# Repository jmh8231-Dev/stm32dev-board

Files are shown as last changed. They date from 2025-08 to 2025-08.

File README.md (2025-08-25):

# STM32F407ZETx 개발보드

**STM32F407ZETx** MCU를 중심으로 DS3231(RTC), VS1003(Audio Codec), microSD(4‑bit SDIO),
SN65HVD230(CAN), USB‑to‑TTL, **DP83848(Ethernet PHY)** 등을 온보드로 구성하고
대형 **브레드보드**와 12 V/5 V/3.3 V 전원 및 **SPI/I²C/PWM 헤더**를 둘러 배치한 실습·프로토타이핑 전용 보드입니다.

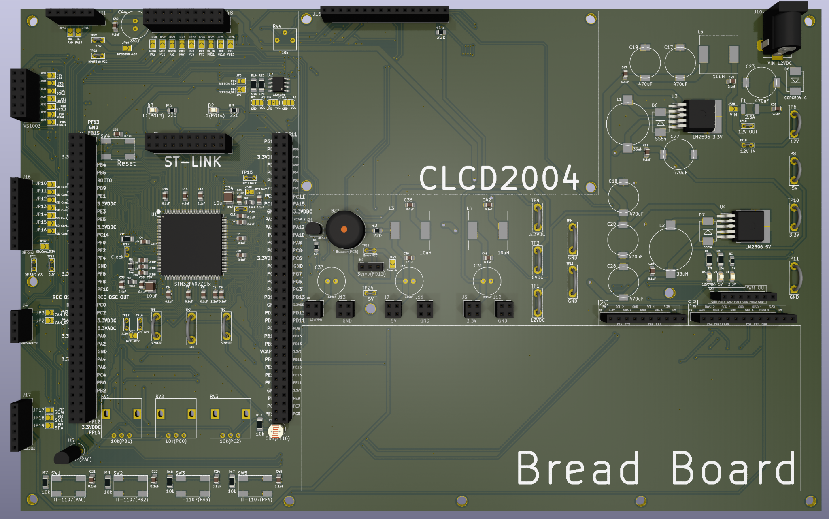
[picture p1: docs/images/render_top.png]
3D Render


---

## 1. 보드 하이라이트

- **MCU**: STM32F407ZETx (LQFP‑144), 8/16 MHz 외부 크리스털, ST‑LINK 20‑핀
- **전원 트리**: 12 V DC 잭 입력 → **LM2596‑5 V**, **LM2596‑3.3 V**
  - 브레드보드 주변에 **12 V / 5 V / 3.3 V 전원 핀** 다수 제공
- **통신/네트워킹**
  - **DP83848** 10/100 Ethernet PHY + RJ45
  - **SN65HVD230** CAN 트랜시버
  - **USB‑to‑TTL**(FT232RL 계열)
- **저장/오디오/시간**
  - **microSD(4‑bit SDIO)**, **VS1003** 오디오 코덱, **DS3231 RTC**
- **사용자 입출력**
  - **20×4 캐릭터 LCD(CLCD2004)** 장착 영역(백라이트 제어)
  - **브레드보드** 장착(보드 일체), 주변에 **SPI/I²C/PWM 헤더** 배치
  - 가변저항/버튼/버저 등 실습용 풋프린트
- **확장성**: 각 인터페이스에 테스트 포인트/점퍼 제공

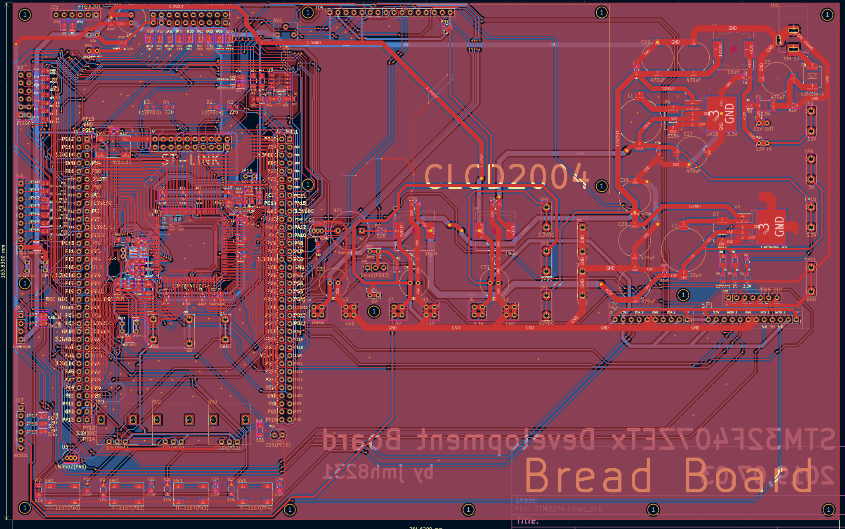
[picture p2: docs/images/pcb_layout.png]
PCB Layout


---

## 2. 주변장치 매핑 요약

| 기능 | 부품/모듈 | 인터페이스 | 비고 |
|---|---|---|---|
| Ethernet | TI **DP83848** | RMII/MII | RJ45, 링크 LED |
| CAN | TI **SN65HVD230** | CAN | 종단저항 점퍼 |
| Audio | **VS1003** | SPI / I²S | Sine test 지원 |
| Storage | microSD | **4‑bit SDIO** | 카드 감지/쓰기보호 |
| RTC | **DS3231** | I²C | 코인셀 백업 |
| USB‑UART | **FT232RL** | USB‑CDC | 부트 로그/쉘 |
| LCD | **CLCD2004** | 병렬 | 백라이트 제어 |
| Breadboard | 1열×2면 | — | SPI/I²C/PWM/전원 배치 |

---

## 3. 빠른 시작

1) 12 V 어댑터 연결 → 전원 LED 확인  
2) ST‑LINK 연결 후 예제 펌웨어 다운로드  
3) **Ethernet → CAN → SDIO → I²C(DS3231) → SPI(VS1003)** 순으로 브링업  
4) 브레드보드에 센서/액추에이터 연결 → SPI/I²C/PWM 헤더로 배선  
5) LCD 장착 후 상태/메뉴 표시 구현

---

## 4. 브링업 체크리스트

- **전원 리플/부하 테스트**(5 V/3.3 V)
- **SDIO 4‑bit**: HS 모드, 카드 감지/쓰기 보호 입력 확인
- **RMII/MII**: DP83848 링크/속도/MDIO 확인
- **CAN**: 루프백 → 실선 통신, 종단저항 설정
- **RTC**: DS3231 1 Hz/32 kHz, 온도 보정 레지스터 확인
- **VS1003**: SCI 레지스터 접근, sine test

---

## 5. 파일 트리

```text
stm32f407-devboard/
├─ README.md
└─ docs/
   └─ images/
      ├─ render_top.png
      ├─ pcb_layout.png
      └─ photo_top.jpg
```

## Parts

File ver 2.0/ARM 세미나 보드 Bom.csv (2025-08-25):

Reference | Qty | Value | DNP | Exclude from BOM | Exclude from Board | Footprint | Datasheet
BT1 | 1 | CR2032 |  |  |  | PCB:BAT-HLD-001 | ~
BZ1 | 1 | Buzzer(PE9) |  |  |  | Buzzer_Beeper:Buzzer_12x9.5RM7.6 | ~
C1,C7,C8,C9,C10,C11,C12,C13,C16,C20,C21,C25,C28,C29,C34,C36,C37,C39,C40,C41,C42,C43,C44,C46,C49,C50,C52,C53,C54,C56,C57,C59 | 32 | 0.1uF |  |  |  | Capacitor_SMD:C_0805_2012Metric | ~
C2,C15 | 2 | 0.01uF |  |  |  | Capacitor_SMD:C_0805_2012Metric | ~
C3,C6 | 2 | 2.2uF |  |  |  | Capacitor_SMD:C_0805_2012Metric | ~
C4,C5,C18,C19,C23,C24,C26,C27,C31,C32,C33,C35,C38,C47,C48,C51,C55 | 17 | 10uF |  |  |  | Capacitor_SMD:C_1206_3216Metric | ~
C14 | 1 | 1uF |  |  |  | Capacitor_SMD:C_0805_2012Metric | ~
C17,C22,C45,C58 | 4 | 470uF |  |  |  | PCB:MVG25WV470M | ~
C30 | 1 | 4.7uF |  |  |  | Capacitor_SMD:C_0805_2012Metric | ~
D1,D7 | 2 | M1 |  |  |  | Diode_SMD:D_SMA | ~
D2 | 1 | Rx |  |  |  | LED_SMD:LED_0805_2012Metric | ~
D3 | 1 | Tx |  |  |  | LED_SMD:LED_0805_2012Metric | ~
D4 | 1 | LD1(PB4) |  |  |  | LED_SMD:LED_0805_2012Metric | ~
D5 | 1 | LD2(PB5) |  |  |  | LED_SMD:LED_0805_2012Metric | ~
D6 | 1 | USB OC |  |  |  | LED_SMD:LED_0805_2012Metric | ~
D8 | 1 | 3.3V |  |  |  | LED_SMD:LED_0805_2012Metric | ~
D9 | 1 | 5V |  |  |  | LED_SMD:LED_0805_2012Metric | ~
DS1 | 1 | CLCD 2004 |  |  |  | PCB:LCD-20x4 | http://www.wincomlcd.com/pdf/WC1602A-SFYLYHTC06.pdf
EEPROM1 | 1 | AT24C256 |  |  |  | Package_SO:SOIC-8_3.9x4.9mm_P1.27mm | https://www.onsemi.cn/PowerSolutions/document/CAT24C256-D.PDF
F1 | 1 | 500mA |  |  |  | Inductor_SMD:L_1210_3225Metric | ~
FB2,FB3,FB4,FB5,FB6,FB7,FB8,FB9,FB10,FB11 | 10 | Bead |  |  |  | Inductor_SMD:L_0805_2012Metric | ~
J1 | 1 | ST-Link |  |  |  | Connector_IDC:IDC-Header_2x10_P2.54mm_Vertical | ~
J2 | 1 | USB Type C |  |  |  | Connector_USB:USB_C_Receptacle_HRO_TYPE-C-31-M-12 | https://www.usb.org/sites/default/files/documents/usb_type-c.zip
J3 | 1 | PIN OUT A |  |  |  | Connector_PinHeader_2.54mm:PinHeader_2x10_P2.54mm_Vertical | ~
J4 | 1 | PIN OUT B |  |  |  | Connector_PinHeader_2.54mm:PinHeader_2x10_P2.54mm_Vertical | ~
J5 | 1 | SG90 |  |  |  | Connector_PinHeader_2.54mm:PinHeader_1x03_P2.54mm_Vertical | ~
J6 | 1 | CAN |  |  |  | Connector_PinHeader_2.54mm:PinHeader_1x02_P2.54mm_Vertical | ~
J7 | 1 | USB_A |  |  |  | Connector_USB:USB_A_Connfly_DS1095 | ~
J8 | 1 | VS1003 |  |  |  | Connector_PinSocket_2.54mm:PinSocket_2x06_P2.54mm_Vertical | ~
JP1 | 1 | BOOT Mode |  |  |  | Jumper:SolderJumper-3_P1.3mm_Open_RoundedPad1.0x1.5mm | ~
Q1 | 1 | BSS138 |  |  |  | Package_TO_SOT_SMD:SOT-23 | https://www.onsemi.com/pub/Collateral/BSS138-D.PDF
R1,R7,R10,R11,R12,R13,R14,R15,R16,R19,R20,R23,R26,R27,R30,R33,R34,R35,R36,R41,R42,R43,R44,R45,R46,R50 | 26 | 10k |  |  |  | Resistor_SMD:R_0805_2012Metric | ~
R2,R3 | 2 | 5.1k |  |  |  | Resistor_SMD:R_0805_2012Metric | ~
R4,R5,R38,R39 | 4 | 22 |  |  |  | Resistor_SMD:R_0805_2012Metric | ~
R6,R29,R37,R40,R47,R48 | 6 | 4.7k |  |  |  | Resistor_SMD:R_0805_2012Metric | ~
R8,R9,R17,R18,R22,R49 | 6 | 1k |  |  |  | Resistor_SMD:R_0805_2012Metric | ~
R21 | 1 | 220 |  |  |  | Resistor_SMD:R_0805_2012Metric | ~
R24 | 1 | 120 |  |  |  | Resistor_SMD:R_0805_2012Metric | ~
R25 | 1 | 330 |  |  |  | Resistor_SMD:R_0805_2012Metric | ~
R28 | 1 | CDS(PC4) |  |  |  | OptoDevice:R_LDR_5.0x4.1mm_P3mm_Vertical | ~
R31 | 1 | 47k |  |  |  | Resistor_SMD:R_0805_2012Metric | ~
R32 | 1 | 620 |  |  |  | Resistor_SMD:R_0805_2012Metric | ~
RV1 | 1 | 10k |  |  |  | PCB:3362P-103LF | ~
RV2 | 1 | 10k(PA2) |  |  |  | PCB:RV09H20SQ-B10K | ~
RV3 | 1 | 10k(PA3) |  |  |  | PCB:RV09H20SQ-B10K | ~
RV4 | 1 | 10k(PA4) |  |  |  | PCB:RV09H20SQ-B10K | ~
SD1 | 1 | SD Card |  |  |  | PCB:AMPHENOL_GSD090012SEU
SW1 | 1 | Main MCU Reset |  |  |  | PCB:SW_SMD_IT-1107 | ~
SW2 | 1 | WiFi Module Reset |  |  |  | PCB:SW_SMD_IT-1107 | ~
SW3 | 1 | SW1(PC0) |  |  |  | PCB:SW_SMD_IT-1107 | ~
SW4 | 1 | SW2(PC1) |  |  |  | PCB:SW_SMD_IT-1107 | ~
SW5 | 1 | SW3(PC2) |  |  |  | PCB:SW_SMD_IT-1107 | ~
SW6 | 1 | SW4(PC3) |  |  |  | PCB:SW_SMD_IT-1107 | ~
Temp1,Temp2 | 2 | AS6221 |  |  |  | Package_CSP:WLCSP-6_1.4x1.0mm_P0.4mm
TP1 | 1 | TCXO 12MHz |  |  |  | TestPoint:TestPoint_Pad_D1.5mm | ~
TP2 | 1 | Buzzer(PE9) |  |  |  | TestPoint:TestPoint_Pad_D1.5mm | ~
TP3 | 1 | SG90(PB3) |  |  |  | TestPoint:TestPoint_Pad_D1.5mm | ~
TP4 | 1 | RTC BAT |  |  |  | TestPoint:TestPoint_Pad_D1.5mm | ~
TP5 | 1 | +3.3V |  |  |  | TestPoint:TestPoint_Pad_D1.5mm | ~
TP6,TP7,TP8,TP10 | 4 | GND |  |  |  | TestPoint:TestPoint_2Pads_Pitch5.08mm_Drill1.3mm | ~
TP9 | 1 | +5V |  |  |  | TestPoint:TestPoint_Pad_D1.5mm | ~
TP11,TP12 | 2 | GND | DNP |  | 기판에서 제외됨 | TestPoint:TestPoint_2Pads_Pitch5.08mm_Drill1.3mm | ~
U1 | 1 | STM32F405VGT6 |  |  |  | Package_QFP:LQFP-100_14x14mm_P0.5mm | https://www.st.com/resource/en/datasheet/stm32f405vg.pdf
U2 | 1 | 12MHz |  |  |  | PCB:ECS-TXO-2016
U3 | 1 | TVS |  |  |  | Package_TO_SOT_SMD:SOT-23-6 | https://www.we-online.com/components/products/datasheet/82400102.pdf
U4 | 1 | FT232RL |  |  |  | Package_SO:SSOP-28_5.3x10.2mm_P0.65mm | https://www.ftdichip.com/Support/Documents/DataSheets/ICs/DS_FT232R.pdf
U5 | 1 | ESP-12F |  |  |  | RF_Module:ESP-12E | http://wiki.ai-thinker.com/_media/esp8266/esp8266_series_modules_user_manual_v1.1.pdf
U6 | 1 | SN65HVD231 |  |  |  | Package_SO:SOIC-8_3.9x4.9mm_P1.27mm | http://www.ti.com/lit/ds/symlink/sn65hvd230.pdf
U7 | 1 | STMPS2141STR |  |  |  | Package_TO_SOT_SMD:SOT-23-5
U8 | 1 | DS3231M |  |  |  | Package_SO:SOIC-16W_7.5x10.3mm_P1.27mm | http://datasheets.maximintegrated.com/en/ds/DS3231.pdf
U9 | 1 | LM1117DT-3.3 |  |  |  | Package_TO_SOT_SMD:TO-252-3_TabPin2 | http://www.ti.com/lit/ds/symlink/lm1117.pdf

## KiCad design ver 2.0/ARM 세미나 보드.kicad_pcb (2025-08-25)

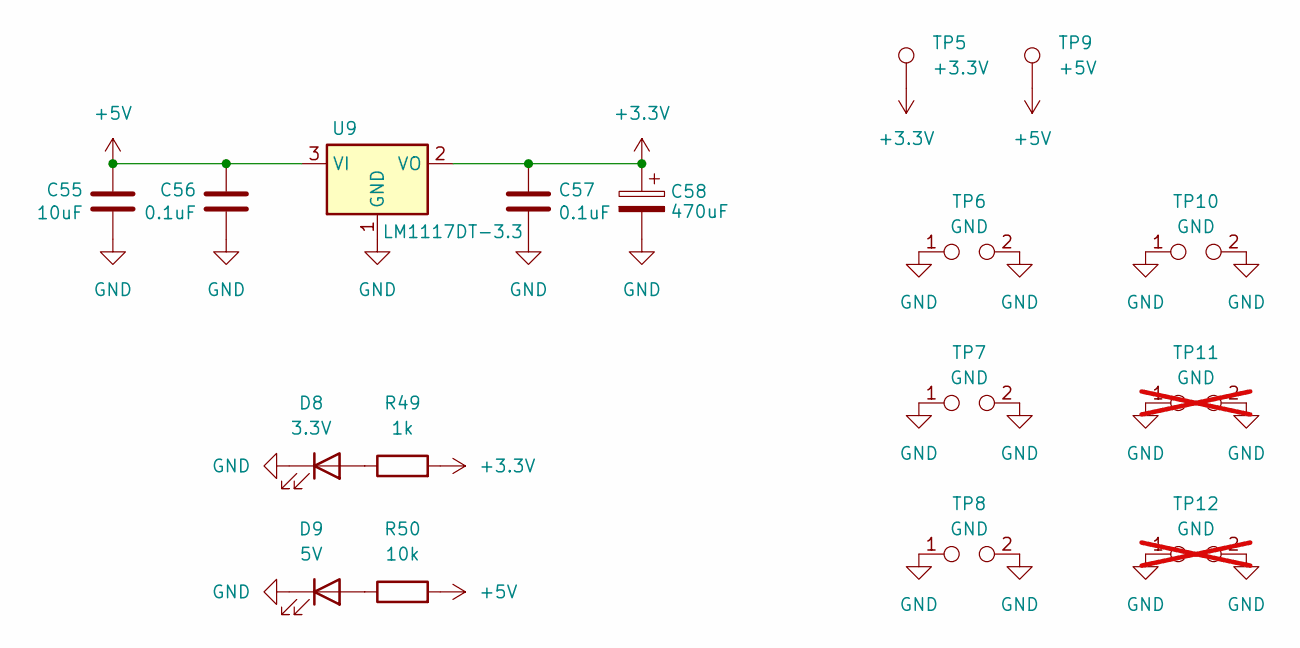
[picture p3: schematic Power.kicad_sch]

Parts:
C55: 10uF; C_1206_3216Metric
C56, C57: 0.1uF; C_0805_2012Metric
C58: 470uF; MVG25WV470M
D8: 3.3V; LED_0805_2012Metric
D9: 5V; LED_0805_2012Metric
R49: 1k; R_0805_2012Metric
R50: 10k; R_0805_2012Metric
TP5: +3.3V; TestPoint_Pad_D1.5mm
TP6, TP7, TP8, TP10: GND; TestPoint_2Pads_Pitch5.08mm_Drill1.3mm
TP9: +5V; TestPoint_Pad_D1.5mm
TP11, TP12: GND; TestPoint_2Pads_Pitch5.08mm_Drill1.3mm; not fitted
U9: LM1117DT-3.3; TO-252-3_TabPin2

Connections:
+3.3V: C57.2, C58.1, R49.2, TP5.1, U9.2 (VO); also elsewhere on the board
+5V: C55.2, C56.2, R50.2, TP9.1, U9.3 (VI); also elsewhere on the board
GND: C55.1, C56.1, C57.1, C58.2, D8.1 (K), D9.1 (K), TP6.1, TP6.2, TP7.1, TP7.2, TP8.1, TP8.2, TP10.1, TP10.2, TP11.1, TP11.2, TP12.1, TP12.2, U9.1 (GND); also elsewhere on the board
unnamed: D8.2 (A), R49.1
unnamed: D9.2 (A), R50.1

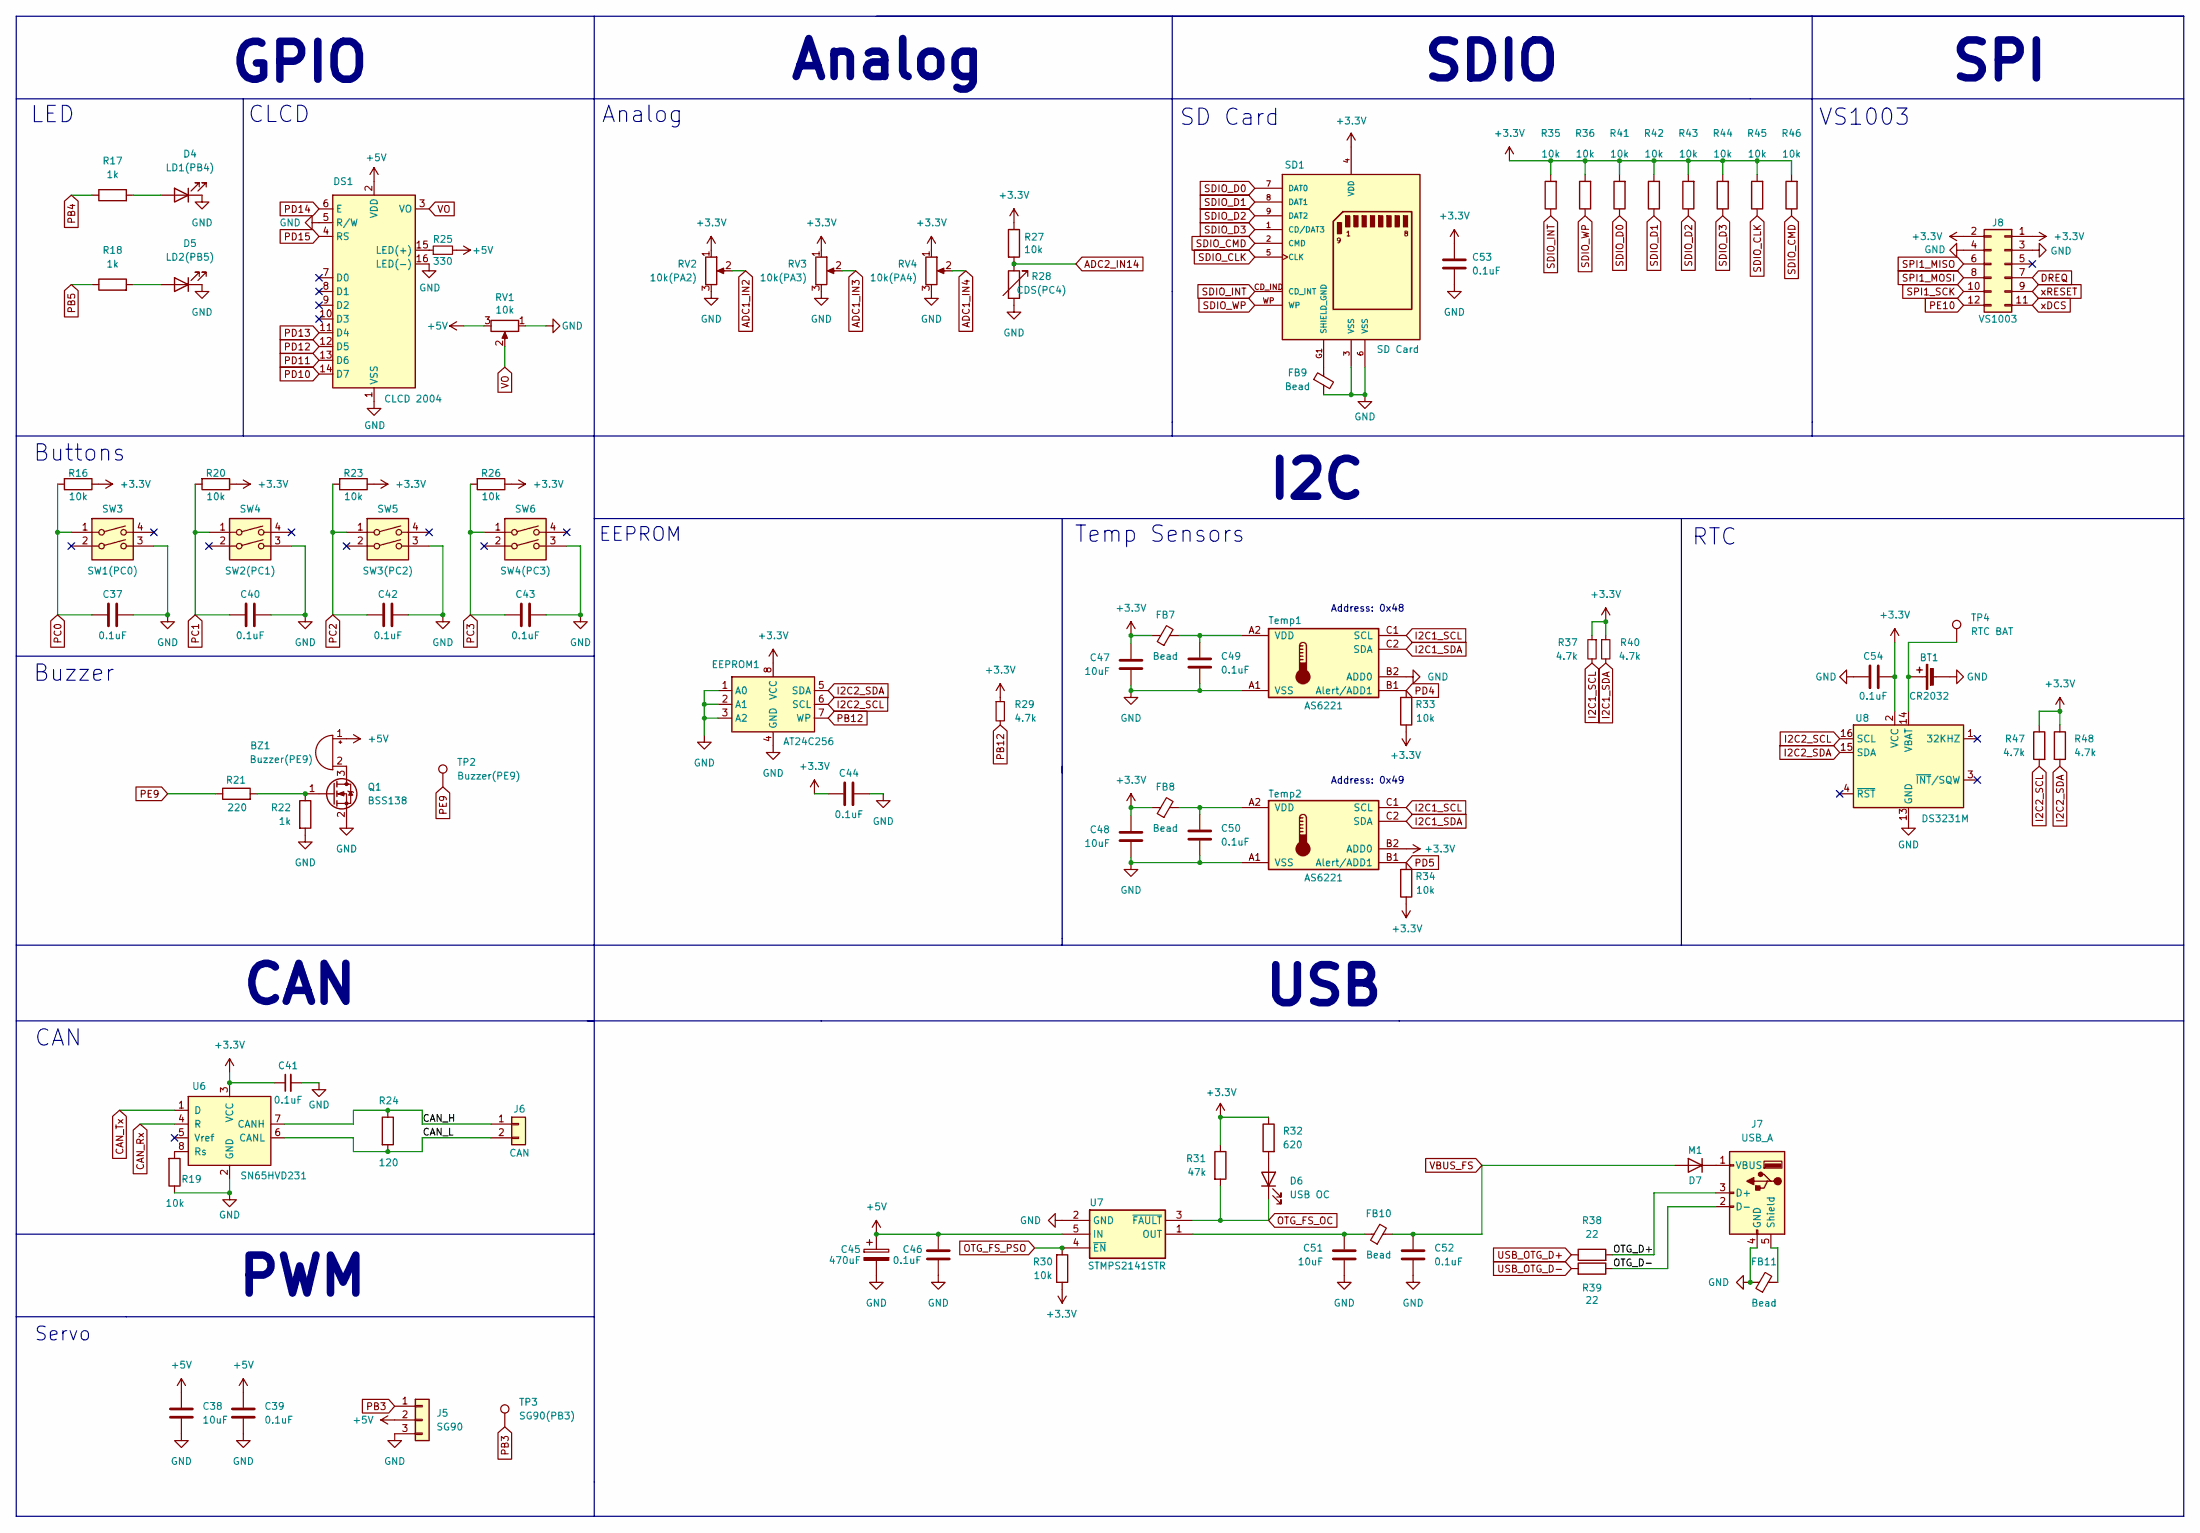
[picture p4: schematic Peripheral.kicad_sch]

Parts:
BT1: CR2032; BAT-HLD-001
BZ1: Buzzer(PE9); Buzzer_12x9.5RM7.6
C37, C39, C40, C41, C42, C43, C44, C46, C49, C50, C52, C53, C54: 0.1uF; C_0805_2012Metric
C38, C47, C48, C51: 10uF; C_1206_3216Metric
C45: 470uF; MVG25WV470M
D4: LD1(PB4); LED_0805_2012Metric
D5: LD2(PB5); LED_0805_2012Metric
D6: USB OC; LED_0805_2012Metric
D7: M1; D_SMA
DS1: CLCD 2004; LCD-20x4
EEPROM1: AT24C256; SOIC-8_3.9x4.9mm_P1.27mm
FB7, FB8, FB9, FB10, FB11: Bead; L_0805_2012Metric
J5: SG90; PinHeader_1x03_P2.54mm_Vertical
J6: CAN; PinHeader_1x02_P2.54mm_Vertical
J7: USB_A; USB_A_Connfly_DS1095
J8: VS1003; PinSocket_2x06_P2.54mm_Vertical
Q1: BSS138; SOT-23
R16, R19, R20, R23, R26, R27, R30, R33, R34, R35, R36, R41, R42, R43, R44, R45, R46: 10k; R_0805_2012Metric
R17, R18, R22: 1k; R_0805_2012Metric
R21: 220; R_0805_2012Metric
R24: 120; R_0805_2012Metric
R25: 330; R_0805_2012Metric
R28: CDS(PC4); R_LDR_5.0x4.1mm_P3mm_Vertical
R29, R37, R40, R47, R48: 4.7k; R_0805_2012Metric
R31: 47k; R_0805_2012Metric
R32: 620; R_0805_2012Metric
R38, R39: 22; R_0805_2012Metric
RV1: 10k; 3362P-103LF
RV2: 10k(PA2); RV09H20SQ-B10K
RV3: 10k(PA3); RV09H20SQ-B10K
RV4: 10k(PA4); RV09H20SQ-B10K
SD1: SD Card; AMPHENOL_GSD090012SEU; PARTREV E
SW3: SW1(PC0); SW_SMD_IT-1107
SW4: SW2(PC1); SW_SMD_IT-1107
SW5: SW3(PC2); SW_SMD_IT-1107
SW6: SW4(PC3); SW_SMD_IT-1107
TP2: Buzzer(PE9); TestPoint_Pad_D1.5mm
TP3: SG90(PB3); TestPoint_Pad_D1.5mm
TP4: RTC BAT; TestPoint_Pad_D1.5mm
Temp1, Temp2: AS6221; WLCSP-6_1.4x1.0mm_P0.4mm
U6: SN65HVD231; SOIC-8_3.9x4.9mm_P1.27mm
U7: STMPS2141STR; SOT-23-5
U8: DS3231M; SOIC-16W_7.5x10.3mm_P1.27mm

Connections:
+3.3V: C41.1, C44.1, C47.2, C48.2, C53.1, C54.2, EEPROM1.8 (VCC), FB7.1, FB8.1, J8.1, J8.2, R16.1, R20.1, R23.1, R26.1, R27.1, R29.1, R30.1, R31.1, R32.1, R33.1, R34.1, R35.2, R36.2, R37.1, R40.1, R41.2, R42.2, R43.2, R44.2, R45.2, R46.2, R47.1, R48.1, RV2.1, RV3.1, RV4.1, SD1.4 (VDD), Temp2.B2 (ADD0), U6.3 (VCC), U8.2 (VCC); also elsewhere on the board
+5V: BZ1.1 (+), C38.1, C39.1, C45.1, C46.1, DS1.2 (VDD), J5.2, R25.2, RV1.3, U7.5 (IN); also elsewhere on the board
/Peripheral/CAN_H: J6.1, R24.1, U6.7 (CANH)
/Peripheral/CAN_L: J6.2, R24.2, U6.6 (CANL)
/Peripheral/OTG_D+: J7.3 (D+), R38.2
/Peripheral/OTG_D-: J7.2 (D-), R39.1
ADC1_IN2: RV2.2; also elsewhere on the board
ADC1_IN3: RV3.2; also elsewhere on the board
ADC1_IN4: RV4.2; also elsewhere on the board
ADC2_IN14: R27.2, R28.1; also elsewhere on the board
CAN_Rx: U6.4 (R); also elsewhere on the board
CAN_Tx: U6.1 (D); also elsewhere on the board
DREQ: J8.7; also elsewhere on the board
GND: BT1.2 (-), C37.2, C38.2, C39.2, C40.2, C41.2, C42.2, C43.2, C44.2, C45.2, C46.2, C47.1, C48.1, C49.2, C50.2, C51.1, C52.2, C53.2, C54.1, D4.1 (K), D5.1 (K), DS1.1 (VSS), DS1.5 (R/W), DS1.16 (LED(-)), EEPROM1.1 (A0), EEPROM1.2 (A1), EEPROM1.3 (A2), EEPROM1.4 (GND), FB9.2, FB11.1, J5.3, J7.4 (GND), J8.3, J8.4, Q1.2 (S), R19.1, R22.2, R28.2, RV1.1, RV2.3, RV2.4, RV2.5, RV3.3, RV3.4, RV3.5, RV4.3, RV4.4, RV4.5, SD1.3 (VSS), SD1.6 (VSS), SW3.3, SW4.3, SW5.3, SW6.3, Temp1.A1 (VSS), Temp1.B2 (ADD0), Temp2.A1 (VSS), U6.2 (GND), U7.2 (GND), U8.5 (GND), U8.6 (GND), U8.7 (GND), U8.8 (GND), U8.9 (GND), U8.10 (GND), U8.11 (GND), U8.12 (GND), U8.13 (GND); also elsewhere on the board
I2C1_SCL: R37.2, Temp1.C1 (SCL), Temp2.C1 (SCL); also elsewhere on the board
I2C1_SDA: R40.2, Temp1.C2 (SDA), Temp2.C2 (SDA); also elsewhere on the board
I2C2_SCL: EEPROM1.6 (SCL), R47.2, U8.16 (SCL); also elsewhere on the board
I2C2_SDA: EEPROM1.5 (SDA), R48.2, U8.15 (SDA); also elsewhere on the board
unnamed: BT1.1 (+), TP4.1, U8.14 (VBAT)
unnamed: BZ1.2 (-), Q1.3 (D)
unnamed: D4.2 (A), R17.2
unnamed: D5.2 (A), R18.2
unnamed: D6.2 (A), R32.2
unnamed: D7.1 (K), J7.1 (VBUS)
unnamed: DS1.15 (LED(+)), R25.1
unnamed: FB11.2, J7.5 (Shield)
unnamed: Q1.1 (G), R21.2, R22.1
unnamed: C49.1, FB7.2, Temp1.A2 (VDD)
unnamed: C50.1, FB8.2, Temp2.A2 (VDD)
unnamed: R19.2, U6.8 (Rs)
unnamed: C51.2, FB10.1, U7.1 (OUT)
OTG_FS_OC: D6.1 (K), R31.2, U7.3 (~FAULT); also elsewhere on the board
OTG_FS_PSO: R30.2, U7.4 (~EN); also elsewhere on the board
PB3: J5.1, TP3.1; also elsewhere on the board
PB4: R17.1; also elsewhere on the board
PB5: R18.1; also elsewhere on the board
PB12: EEPROM1.7 (WP), R29.2; also elsewhere on the board
PC0: C37.1, R16.2, SW3.1; also elsewhere on the board
PC1: C40.1, R20.2, SW4.1; also elsewhere on the board
PC2: C42.1, R23.2, SW5.1; also elsewhere on the board
PC3: C43.1, R26.2, SW6.1; also elsewhere on the board
PD4: R33.2, Temp1.B1 (Alert/ADD1); also elsewhere on the board
PD5: R34.2, Temp2.B1 (Alert/ADD1); also elsewhere on the board
PD10: DS1.14 (D7); also elsewhere on the board
PD11: DS1.13 (D6); also elsewhere on the board
PD12: DS1.12 (D5); also elsewhere on the board
PD13: DS1.11 (D4); also elsewhere on the board
PD14: DS1.6 (E); also elsewhere on the board
PD15: DS1.4 (RS); also elsewhere on the board
PE9: R21.1, TP2.1; also elsewhere on the board
PE10: J8.12; also elsewhere on the board
SDIO_CLK: R45.1, SD1.5 (CLK); also elsewhere on the board
SDIO_CMD: R46.1, SD1.2 (CMD); also elsewhere on the board
SDIO_D0: R41.1, SD1.7 (DAT0); also elsewhere on the board
SDIO_D1: R42.1, SD1.8 (DAT1); also elsewhere on the board
SDIO_D2: R43.1, SD1.9 (DAT2); also elsewhere on the board
SDIO_D3: R44.1, SD1.1 (CD/DAT3); also elsewhere on the board
SDIO_INT: R35.1, SD1.CD_IND (CD_INT); also elsewhere on the board
SDIO_WP: R36.1, SD1.WP; also elsewhere on the board
SHIELD_GND: FB9.1, SD1.G1 (SHIELD_GND), SD1.G2 (SHIELD_GND), SD1.G3 (SHIELD_GND), SD1.G4 (SHIELD_GND)
SPI1_MISO: J8.6; also elsewhere on the board
SPI1_MOSI: J8.8; also elsewhere on the board
SPI1_SCK: J8.10; also elsewhere on the board
USB_OTG_D+: R38.1; also elsewhere on the board
USB_OTG_D-: R39.2; also elsewhere on the board
VBUS_FS: C52.1, D7.2 (A), FB10.2; also elsewhere on the board
VO: DS1.3 (VO), RV1.2
xDCS: J8.11; also elsewhere on the board
xRESET: J8.9; also elsewhere on the board

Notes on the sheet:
Address: 0x48
CLCD
Analog
Buttons
Buzzer
Servo
VS1003
RTC
EEPROM
LED
CAN
SPI
I2C
Temp Sensors
USB
SD Card
PWM
GPIO
SDIO
Address: 0x49

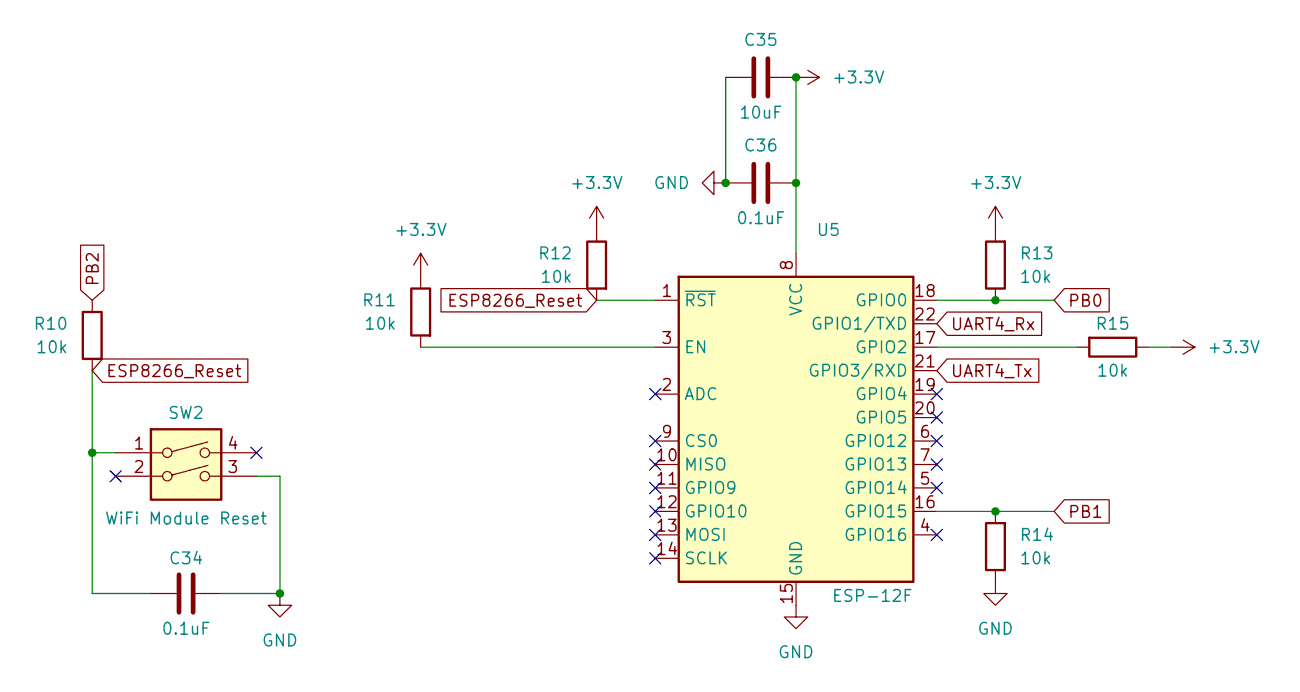
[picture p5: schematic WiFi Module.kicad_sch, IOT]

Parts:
C34, C36: 0.1uF; C_0805_2012Metric
C35: 10uF; C_1206_3216Metric
R10, R11, R12, R13, R14, R15: 10k; R_0805_2012Metric
SW2: WiFi Module Reset; SW_SMD_IT-1107
U5: ESP-12F; ESP-12E

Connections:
+3.3V: C35.2, C36.2, R11.1, R12.1, R13.2, R15.1, U5.8 (VCC); also elsewhere on the board
ESP8266_Reset: C34.1, R10.2, R12.2, SW2.1, U5.1 (~RST)
GND: C34.2, C35.1, C36.1, R14.1, SW2.3, U5.15 (GND); also elsewhere on the board
unnamed: R11.2, U5.3 (EN)
unnamed: R15.2, U5.17 (GPIO2)
PB0: R13.1, U5.18 (GPIO0); also elsewhere on the board
PB1: R14.2, U5.16 (GPIO15); also elsewhere on the board
PB2: R10.1; also elsewhere on the board
UART4_Rx: U5.22 (GPIO1/TXD); also elsewhere on the board
UART4_Tx: U5.21 (GPIO3/RXD); also elsewhere on the board

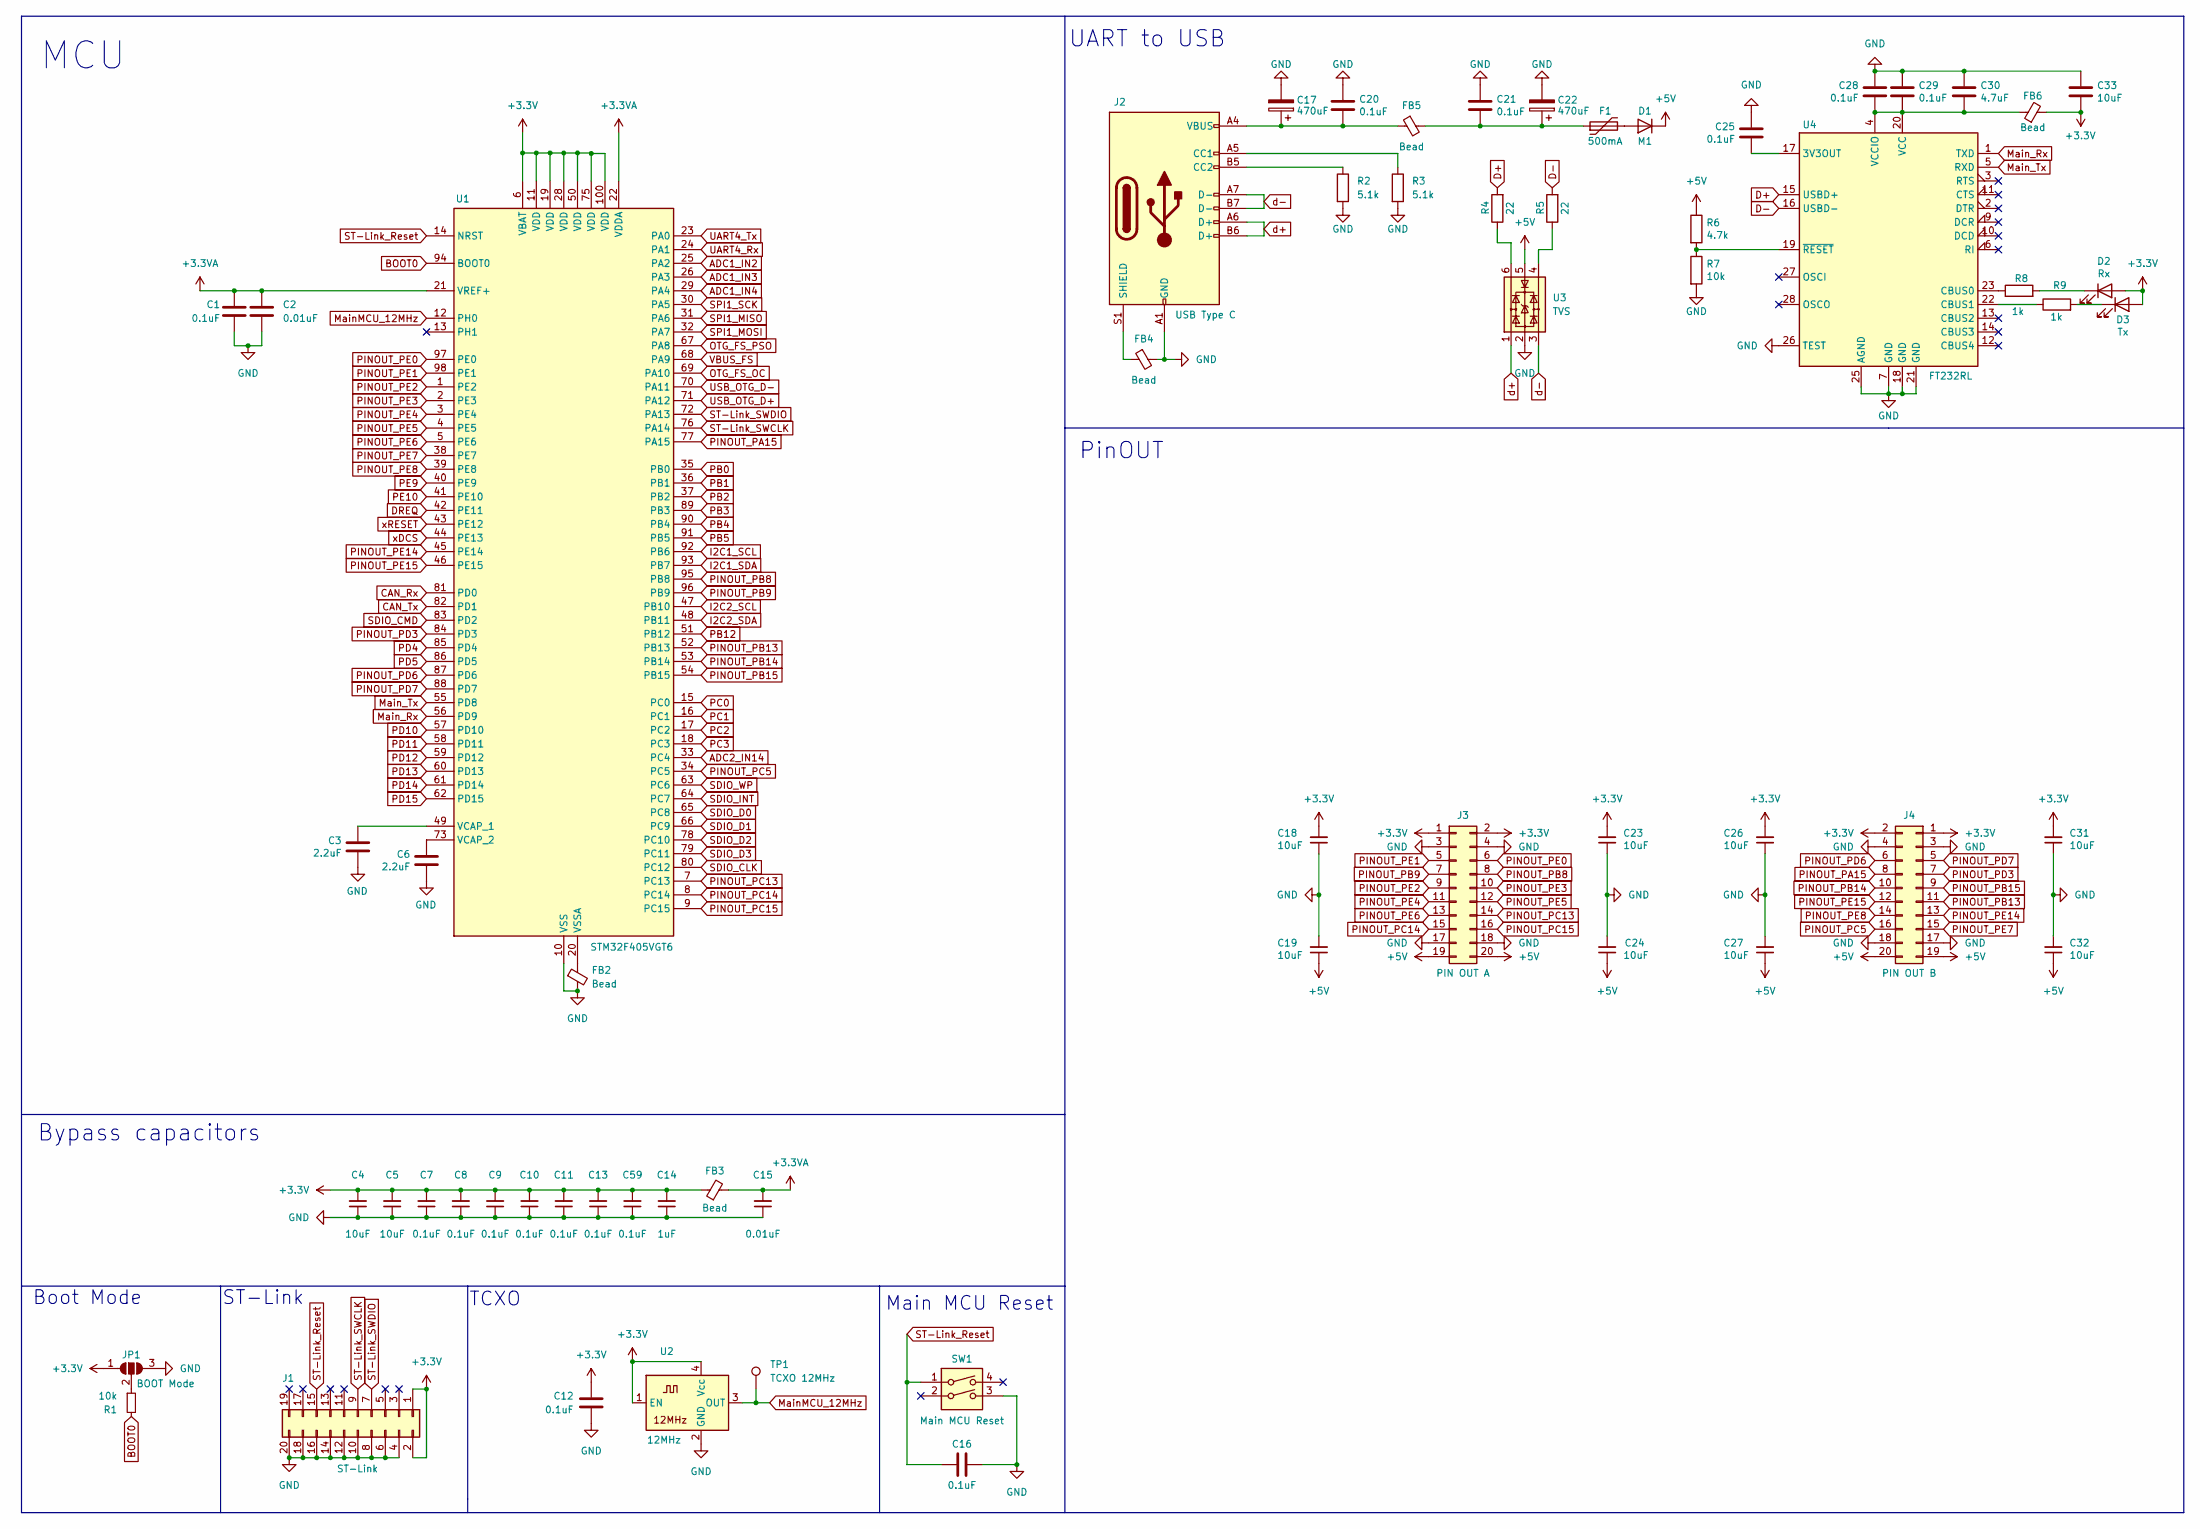
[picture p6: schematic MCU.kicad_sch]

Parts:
C1, C7, C8, C9, C10, C11, C12, C13, C16, C20, C21, C25, C28, C29, C59: 0.1uF; C_0805_2012Metric
C2, C15: 0.01uF; C_0805_2012Metric
C3, C6: 2.2uF; C_0805_2012Metric
C4, C5, C18, C19, C23, C24, C26, C27, C31, C32, C33: 10uF; C_1206_3216Metric
C14: 1uF; C_0805_2012Metric
C17, C22: 470uF; MVG25WV470M
C30: 4.7uF; C_0805_2012Metric
D1: M1; D_SMA
D2: Rx; LED_0805_2012Metric
D3: Tx; LED_0805_2012Metric
F1: 500mA; L_1210_3225Metric
FB2, FB3, FB4, FB5, FB6: Bead; L_0805_2012Metric
J1: ST-Link; IDC-Header_2x10_P2.54mm_Vertical
J2: USB Type C; USB_C_Receptacle_HRO_TYPE-C-31-M-12
J3: PIN OUT A; PinHeader_2x10_P2.54mm_Vertical
J4: PIN OUT B; PinHeader_2x10_P2.54mm_Vertical
JP1: BOOT Mode; SolderJumper-3_P1.3mm_Open_RoundedPad1.0x1.5mm
R1, R7: 10k; R_0805_2012Metric
R2, R3: 5.1k; R_0805_2012Metric
R4, R5: 22; R_0805_2012Metric
R6: 4.7k; R_0805_2012Metric
R8, R9: 1k; R_0805_2012Metric
SW1: Main MCU Reset; SW_SMD_IT-1107
TP1: TCXO 12MHz; TestPoint_Pad_D1.5mm
U1: STM32F405VGT6; LQFP-100_14x14mm_P0.5mm
U2: 12MHz; ECS-TXO-2016
U3: TVS; SOT-23-6
U4: FT232RL; SSOP-28_5.3x10.2mm_P0.65mm

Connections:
+3.3V: C4.2, C5.2, C7.2, C8.2, C9.2, C10.2, C11.2, C12.1, C13.2, C14.2, C18.2, C23.2, C26.2, C31.2, C33.1, C59.2, D2.2 (A), D3.2 (A), FB3.1, FB6.2, J1.1, J1.2, J3.1, J3.2, J4.1, J4.2, JP1.1 (A), U1.6 (VBAT), U1.11 (VDD), U1.19 (VDD), U1.28 (VDD), U1.50 (VDD), U1.75 (VDD), U1.100 (VDD), U2.1 (EN), U2.4 (Vcc); also elsewhere on the board
+3.3VA: C1.2, C2.2, C15.2, FB3.2, U1.21 (VREF+), U1.22 (VDDA)
+5V: C19.1, C24.1, C27.1, C32.1, D1.1 (K), J3.19, J3.20, J4.19, J4.20, R6.1, U3.5; also elsewhere on the board
ADC1_IN2: U1.25 (PA2); also elsewhere on the board
ADC1_IN3: U1.26 (PA3); also elsewhere on the board
ADC1_IN4: U1.29 (PA4); also elsewhere on the board
ADC2_IN14: U1.33 (PC4); also elsewhere on the board
BOOT0: R1.2, U1.94 (BOOT0)
CAN_Rx: U1.81 (PD0); also elsewhere on the board
CAN_Tx: U1.82 (PD1); also elsewhere on the board
D+: R4.2, U4.15 (USBD+)
D-: R5.2, U4.16 (USBD-)
DREQ: U1.42 (PE11); also elsewhere on the board
GND: C1.1, C2.1, C3.2, C4.1, C5.1, C6.2, C7.1, C8.1, C9.1, C10.1, C11.1, C12.2, C13.1, C14.1, C15.1, C16.2, C17.2, C18.1, C19.2, C20.2, C21.2, C22.2, C23.1, C24.2, C25.2, C26.1, C27.2, C28.2, C29.2, C30.2, C31.1, C32.2, C33.2, C59.1, FB2.2, FB4.2, J1.4, J1.6, J1.8, J1.10, J1.12, J1.14, J1.16, J1.18, J1.20, J2.A1 (GND), J2.A12 (GND), J2.B1 (GND), J2.B12 (GND), J3.3, J3.4, J3.17, J3.18, J4.3, J4.4, J4.17, J4.18, JP1.3 (B), R2.2, R3.2, R7.2, SW1.3, U1.10 (VSS), U1.27 (VSS), U1.74 (VSS), U1.99 (VSS), U2.2 (GND), U3.2, U4.7 (GND), U4.18 (GND), U4.21 (GND), U4.25 (AGND), U4.26 (TEST); also elsewhere on the board
I2C1_SCL: U1.92 (PB6); also elsewhere on the board
I2C1_SDA: U1.93 (PB7); also elsewhere on the board
I2C2_SCL: U1.47 (PB10); also elsewhere on the board
I2C2_SDA: U1.48 (PB11); also elsewhere on the board
MainMCU_12MHz: TP1.1, U1.12 (PH0), U2.3 (OUT)
Main_Rx: U1.56 (PD9), U4.1 (TXD)
Main_Tx: U1.55 (PD8), U4.5 (RXD)
unnamed: C17.1, C20.1, FB5.1, J2.A4 (VBUS), J2.A9 (VBUS), J2.B4 (VBUS), J2.B9 (VBUS)
unnamed: C21.1, C22.1, F1.1, FB5.2
unnamed: D1.2 (A), F1.2
unnamed: D2.1 (K), R8.2
unnamed: D3.1 (K), R9.2
unnamed: J2.A5 (CC1), R3.1
unnamed: J2.B5 (CC2), R2.1
unnamed: FB4.1, J2.S1 (SHIELD)
unnamed: JP1.2 (C), R1.1
unnamed: R4.1, U3.6
unnamed: R5.1, U3.4
unnamed: C3.1, U1.49 (VCAP_1)
unnamed: C6.1, U1.73 (VCAP_2)
unnamed: FB2.1, U1.20 (VSSA)
unnamed: C25.1, U4.17 (3V3OUT)
unnamed: R8.1, U4.23 (CBUS0)
unnamed: R9.1, U4.22 (CBUS1)
unnamed: C28.1, C29.1, C30.1, FB6.1, U4.4 (VCCIO), U4.20 (VCC)
unnamed: R6.2, R7.1, U4.19 (~RESET)
OTG_FS_OC: U1.69 (PA10); also elsewhere on the board
OTG_FS_PSO: U1.67 (PA8); also elsewhere on the board
PB0: U1.35 (PB0); also elsewhere on the board
PB1: U1.36 (PB1); also elsewhere on the board
PB2: U1.37 (PB2); also elsewhere on the board
PB3: U1.89 (PB3); also elsewhere on the board
PB4: U1.90 (PB4); also elsewhere on the board
PB5: U1.91 (PB5); also elsewhere on the board
PB12: U1.51 (PB12); also elsewhere on the board
PC0: U1.15 (PC0); also elsewhere on the board
PC1: U1.16 (PC1); also elsewhere on the board
PC2: U1.17 (PC2); also elsewhere on the board
PC3: U1.18 (PC3); also elsewhere on the board
PD4: U1.85 (PD4); also elsewhere on the board
PD5: U1.86 (PD5); also elsewhere on the board
PD10: U1.57 (PD10); also elsewhere on the board
PD11: U1.58 (PD11); also elsewhere on the board
PD12: U1.59 (PD12); also elsewhere on the board
PD13: U1.60 (PD13); also elsewhere on the board
PD14: U1.61 (PD14); also elsewhere on the board
PD15: U1.62 (PD15); also elsewhere on the board
PE9: U1.40 (PE9); also elsewhere on the board
PE10: U1.41 (PE10); also elsewhere on the board
PINOUT_PA15: J4.8, U1.77 (PA15)
PINOUT_PB8: J3.8, U1.95 (PB8)
PINOUT_PB9: J3.7, U1.96 (PB9)
PINOUT_PB13: J4.11, U1.52 (PB13)
PINOUT_PB14: J4.10, U1.53 (PB14)
PINOUT_PB15: J4.9, U1.54 (PB15)
PINOUT_PC5: J4.16, U1.34 (PC5)
PINOUT_PC13: J3.14, U1.7 (PC13)
PINOUT_PC14: J3.15, U1.8 (PC14)
PINOUT_PC15: J3.16, U1.9 (PC15)
PINOUT_PD3: J4.7, U1.84 (PD3)
PINOUT_PD6: J4.6, U1.87 (PD6)
PINOUT_PD7: J4.5, U1.88 (PD7)
PINOUT_PE0: J3.6, U1.97 (PE0)
PINOUT_PE1: J3.5, U1.98 (PE1)
PINOUT_PE2: J3.9, U1.1 (PE2)
PINOUT_PE3: J3.10, U1.2 (PE3)
PINOUT_PE4: J3.11, U1.3 (PE4)
PINOUT_PE5: J3.12, U1.4 (PE5)
PINOUT_PE6: J3.13, U1.5 (PE6)
PINOUT_PE7: J4.15, U1.38 (PE7)
PINOUT_PE8: J4.14, U1.39 (PE8)
PINOUT_PE14: J4.13, U1.45 (PE14)
PINOUT_PE15: J4.12, U1.46 (PE15)
SDIO_CLK: U1.80 (PC12); also elsewhere on the board
SDIO_CMD: U1.83 (PD2); also elsewhere on the board
SDIO_D0: U1.65 (PC8); also elsewhere on the board
SDIO_D1: U1.66 (PC9); also elsewhere on the board
SDIO_D2: U1.78 (PC10); also elsewhere on the board
SDIO_D3: U1.79 (PC11); also elsewhere on the board
SDIO_INT: U1.64 (PC7); also elsewhere on the board
SDIO_WP: U1.63 (PC6); also elsewhere on the board
SPI1_MISO: U1.31 (PA6); also elsewhere on the board
SPI1_MOSI: U1.32 (PA7); also elsewhere on the board
SPI1_SCK: U1.30 (PA5); also elsewhere on the board
ST-Link_Reset: C16.1, J1.15, SW1.1, U1.14 (NRST)
ST-Link_SWCLK: J1.9, U1.76 (PA14)
ST-Link_SWDIO: J1.7, U1.72 (PA13)
UART4_Rx: U1.24 (PA1); also elsewhere on the board
UART4_Tx: U1.23 (PA0); also elsewhere on the board
USB_OTG_D+: U1.71 (PA12); also elsewhere on the board
USB_OTG_D-: U1.70 (PA11); also elsewhere on the board
VBUS_FS: U1.68 (PA9); also elsewhere on the board
d+: J2.A6 (D+), J2.B6 (D+), U3.1
d-: J2.A7 (D-), J2.B7 (D-), U3.3
xDCS: U1.44 (PE13); also elsewhere on the board
xRESET: U1.43 (PE12); also elsewhere on the board

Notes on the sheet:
UART to USB
Bypass capacitors
TCXO
MCU
Main MCU Reset
Boot Mode
ST-Link
PinOUT

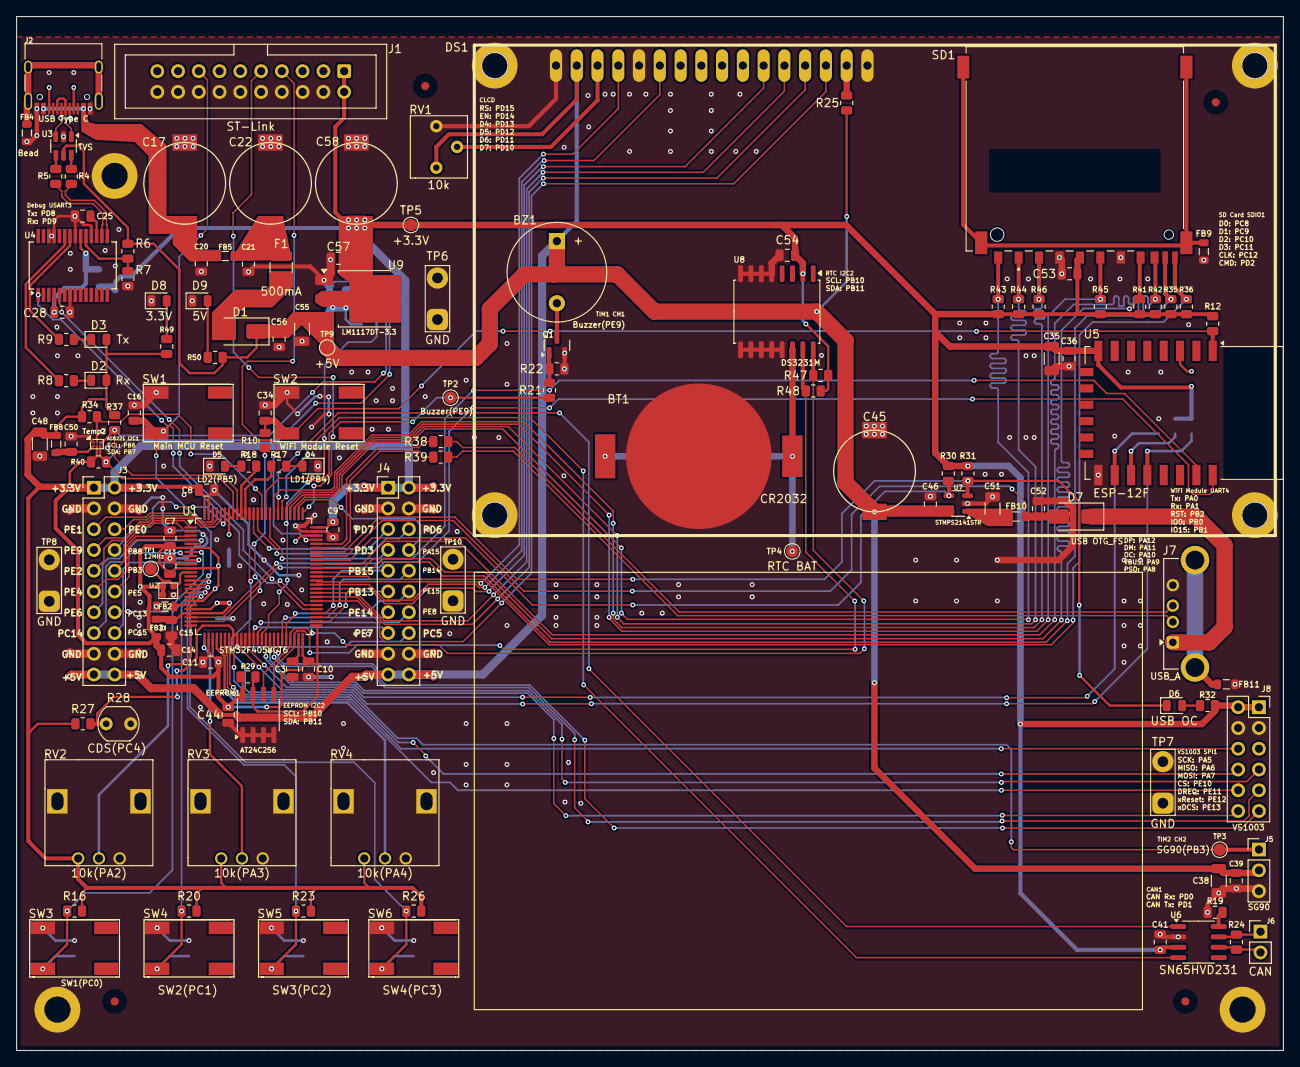
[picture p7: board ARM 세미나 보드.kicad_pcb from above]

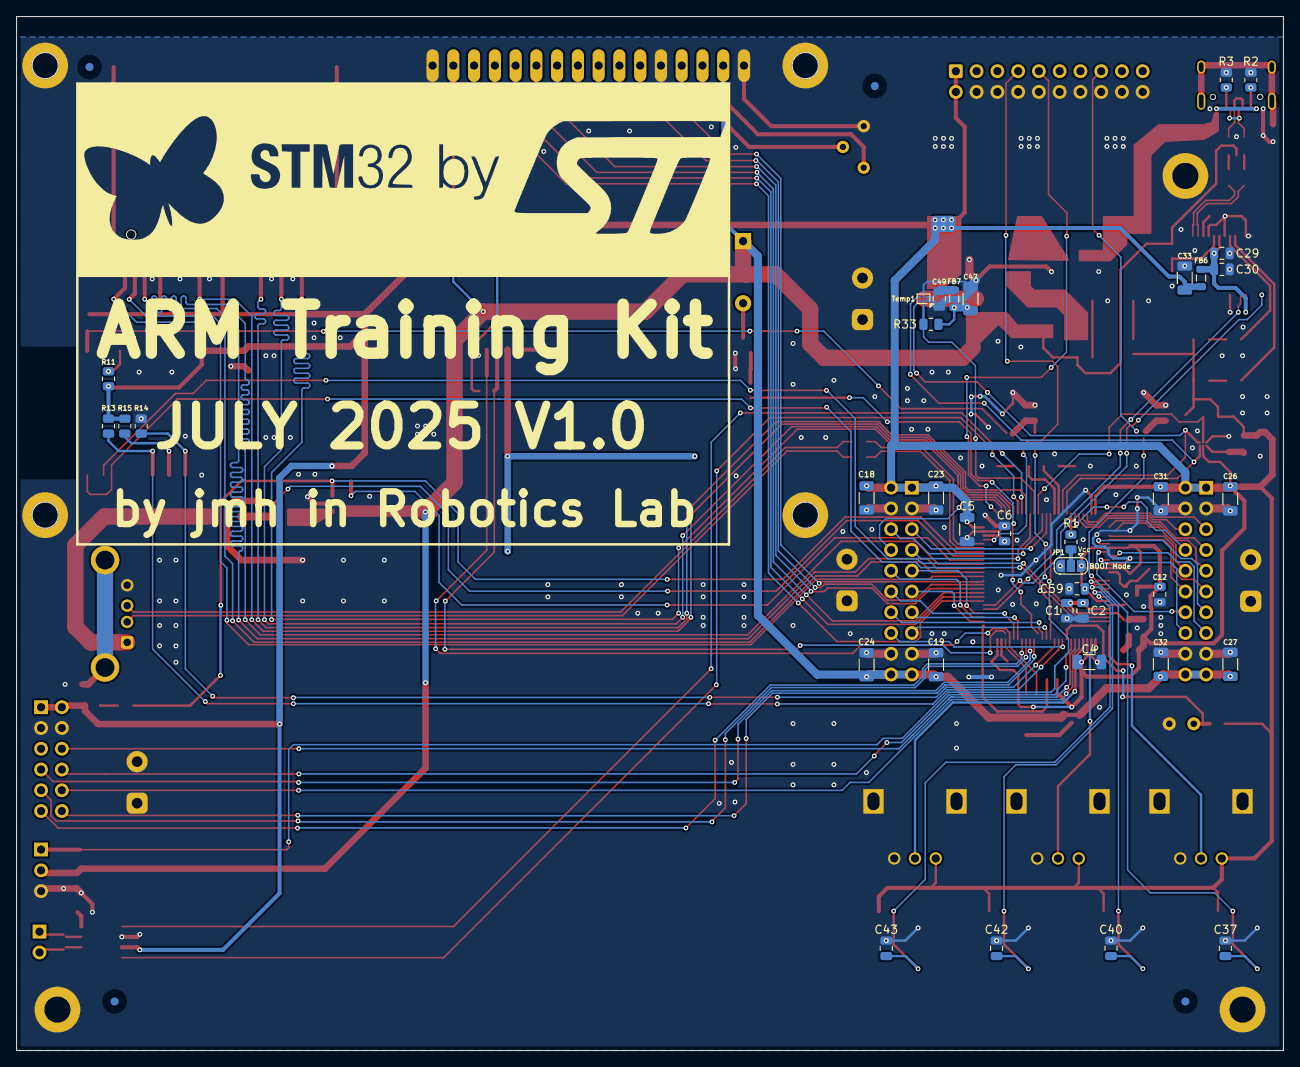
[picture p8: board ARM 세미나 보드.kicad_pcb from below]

Board: 2 copper layers, 155.0 x 126.5 mm, 175 parts (36 on the bottom side), 134 nets.

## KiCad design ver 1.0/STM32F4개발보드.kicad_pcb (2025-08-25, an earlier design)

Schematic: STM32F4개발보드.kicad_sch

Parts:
BZ1: Buzzer(PC6); Buzzer_12x9.5RM7.6
C1, C2: 2.2uF; C_0805_2012Metric_Pad1.15x1.40mm_HandSolder
C3, C4, C5, C6, C7, C8, C9, C10, C11, C12, C13, C14, C15, C16, C21, C22, C24, C25, C26, C29, C30, C35, C36, C38, C39, C40, C41, C42, C43, C45, C46, C47, C48: 0.1uF; C_0805_2012Metric_Pad1.15x1.40mm_HandSolder
C17, C18, C19, C20, C23, C27, C28: 470uF; MVG25WV470M
C31, C32, C33, C44: 330uF; c1
C34, C37: 10uF; C_1210_3225Metric_Pad1.42x2.65mm_HandSolder
D1: 3.3V; LED_0805_2012Metric_Pad1.15x1.40mm_HandSolder
D2: L2(PG14); LED_0805_2012Metric_Pad1.15x1.40mm_HandSolder
D3: L1(PG13); LED_0805_2012Metric_Pad1.15x1.40mm_HandSolder
D4: 5V; LED_0805_2012Metric_Pad1.15x1.40mm_HandSolder
D5: 12V(VIN); LED_0805_2012Metric_Pad1.15x1.40mm_HandSolder
D6, D7: SS54
D8: CGRC504-G; SS54
F1: 2.5A; Fuse_1812_4532Metric_Pad1.30x3.40mm_HandSolder
FB2: Bead
FB3: Bead; L_0805_2012Metric_Pad1.15x1.40mm_HandSolder
J1, J2: PinSocket_2x36_P2.54mm_Vertical
J3: I2C; PinSocket_1x10_P2.54mm_Vertical
J4: SN65HVD230; PinSocket_1x04_P2.54mm_Vertical
J5: SPI; PinSocket_1x12_P2.54mm_Vertical
J6: 3.3V; PinSocket_2x02_P2.54mm_Vertical
J7: 5V; PinSocket_2x02_P2.54mm_Vertical
J8: 12V(VIN); PinSocket_2x02_P2.54mm_Vertical
J9: ST-LINK; PinSocket_2x10_P2.54mm_Vertical
J10: VIN 12VDC; BarrelJack_Horizontal
J11, J12, J13: GND; PinSocket_2x02_P2.54mm_Vertical
J14: DP83848; PinSocket_2x10_P2.54mm_Vertical
J15: CLCD2004; PinSocket_1x16_P2.54mm_Vertical
J16: SD Card; PinSocket_1x09_P2.54mm_Vertical
J17: DS3231; PinSocket_1x06_P2.54mm_Vertical
J18: VS1003; PinSocket_2x06_P2.54mm_Vertical
J19: Servo(PD13); PinSocket_1x03_P2.54mm_Vertical
J20: PWM OUT; PinSocket_1x07_P2.54mm_Vertical
J21: FT232RL; PinSocket_1x06_P2.54mm_Vertical
JP2: CAN_RX; SolderJumper-2_P1.3mm_Open_TrianglePad1.0x1.5mm
JP3: CAN_TX; SolderJumper-2_P1.3mm_Open_TrianglePad1.0x1.5mm
JP4: A1; SolderJumper-3_P1.3mm_Open_RoundedPad1.0x1.5mm
JP5: A0; SolderJumper-3_P1.3mm_Open_RoundedPad1.0x1.5mm
JP6: A2; SolderJumper-3_P1.3mm_Open_RoundedPad1.0x1.5mm
JP7: EEPROM_SCL; SolderJumper-2_P1.3mm_Open_TrianglePad1.0x1.5mm
JP8: EEPROM_SDA; SolderJumper-2_P1.3mm_Open_TrianglePad1.0x1.5mm
JP9: Boot Mode; SolderJumper-3_P1.3mm_Open_RoundedPad1.0x1.5mm
JP10: SD Card_CD; SolderJumper-2_P1.3mm_Open_TrianglePad1.0x1.5mm
JP11: SD Card_D1; SolderJumper-2_P1.3mm_Open_TrianglePad1.0x1.5mm
JP12: SD Card_D2; SolderJumper-2_P1.3mm_Open_TrianglePad1.0x1.5mm
JP13: SD Card_D3; SolderJumper-2_P1.3mm_Open_TrianglePad1.0x1.5mm
JP14: SD Card_CLK; SolderJumper-2_P1.3mm_Open_TrianglePad1.0x1.5mm
JP15: SD Card_CMD; SolderJumper-2_P1.3mm_Open_TrianglePad1.0x1.5mm
JP16: SD Card_D0; SolderJumper-2_P1.3mm_Open_TrianglePad1.0x1.5mm
JP17: SQW; SolderJumper-2_P1.3mm_Open_TrianglePad1.0x1.5mm
JP18: SCL; SolderJumper-2_P1.3mm_Open_TrianglePad1.0x1.5mm
JP19: SDA; SolderJumper-2_P1.3mm_Open_TrianglePad1.0x1.5mm
JP20: MDIO; SolderJumper-2_P1.3mm_Open_TrianglePad1.0x1.5mm
JP21: OSCIN; SolderJumper-2_P1.3mm_Open_TrianglePad1.0x1.5mm
JP22: RX0; SolderJumper-2_P1.3mm_Open_TrianglePad1.0x1.5mm
JP23: TX_EN; SolderJumper-2_P1.3mm_Open_TrianglePad1.0x1.5mm
JP24: TX1; SolderJumper-2_P1.3mm_Open_TrianglePad1.0x1.5mm
JP25: TX0; SolderJumper-2_P1.3mm_Open_TrianglePad1.0x1.5mm
JP26: RX1; SolderJumper-2_P1.3mm_Open_TrianglePad1.0x1.5mm
JP27: CRS; SolderJumper-2_P1.3mm_Open_TrianglePad1.0x1.5mm
JP28: MDC; SolderJumper-2_P1.3mm_Open_TrianglePad1.0x1.5mm
JP29: MISO_1; SolderJumper-2_P1.3mm_Open_TrianglePad1.0x1.5mm
JP30: MOSI_1; SolderJumper-2_P1.3mm_Open_TrianglePad1.0x1.5mm
JP31: SCK_1; SolderJumper-2_P1.3mm_Open_TrianglePad1.0x1.5mm
JP32: CSS; SolderJumper-2_P1.3mm_Open_TrianglePad1.0x1.5mm
JP33: DREQ; SolderJumper-2_P1.3mm_Open_TrianglePad1.0x1.5mm
JP34: xRESET; SolderJumper-2_P1.3mm_Open_TrianglePad1.0x1.5mm
JP35: xDCS; SolderJumper-2_P1.3mm_Open_TrianglePad1.0x1.5mm
JP36: MCU DVCC; SolderJumper-2_P1.3mm_Open_TrianglePad1.0x1.5mm
JP37: MCU AVCC; SolderJumper-2_P1.3mm_Open_TrianglePad1.0x1.5mm
JP38: VIN; SolderJumper-2_P1.3mm_Open_TrianglePad1.0x1.5mm
JP39: SD_Card_3.3V; SolderJumper-2_P1.3mm_Open_TrianglePad1.0x1.5mm
JP40: DP83848 3.3V; SolderJumper-2_P1.3mm_Open_TrianglePad1.0x1.5mm
JP41: TX; SolderJumper-2_P1.3mm_Open_TrianglePad1.0x1.5mm
JP42: RX; SolderJumper-2_P1.3mm_Open_TrianglePad1.0x1.5mm
JP43: Servo 5V; SolderJumper-2_P1.3mm_Open_TrianglePad1.0x1.5mm
L1, L2: 33uH; SRR1806-330M
L3, L4, L5: 10uH; L_12x12mm_H6mm
Q1: BC547; TO-92_Inline
R1: 10k; R_0805_2012Metric_Pad1.15x1.40mm_HandSolder
R2, R3, R4, R16: 220; R_0805_2012Metric_Pad1.15x1.40mm_HandSolder
R5: 1k; R_0805_2012Metric_Pad1.15x1.40mm_HandSolder
R6, R7, R9, R10, R11, R12, R17: 10k; R_1206_3216Metric_Pad1.42x1.75mm_HandSolder
R8: 27k; R_1206_3216Metric_Pad1.42x1.75mm_HandSolder
R13, R14: 4.7k; R_1206_3216Metric_Pad1.42x1.75mm_HandSolder
R15: CDS(PF10); R_LDR_4.9x4.2mm_P2.54mm_Vertical
RV1: 10k(PB1); RV09H20SQ-B10K
RV2: 10k(PC0); RV09H20SQ-B10K
RV3: 10k(PC2); RV09H20SQ-B10K
RV4: 10k; 3362P-103LF
SW1: IT-1107(PA0); SW_SMD_IT-1107
SW2: IT-1107(PB2); SW_SMD_IT-1107
SW3: IT-1107(PA3); SW_SMD_IT-1107
SW4: Reset; SW_SMD_IT-1107
SW5: IT-1107(PF4); SW_SMD_IT-1107
TP1: 12VDC; TestPoint_Bridge_Pitch6.35mm_Drill1.3mm
TP2: 3.3VDDC; TestPoint_Bridge_Pitch6.35mm_Drill1.3mm
TP3: 5VDC; TestPoint_Bridge_Pitch6.35mm_Drill1.3mm
TP4: 3.3VDC; TestPoint_Bridge_Pitch6.35mm_Drill1.3mm
TP5: 3.3VADC; TestPoint_Bridge_Pitch6.35mm_Drill1.3mm
TP6: 12V; TestPoint_Bridge_Pitch6.35mm_Drill1.3mm
TP7, TP9, TP11, TP12: GND; TestPoint_Bridge_Pitch7.62mm_Drill1.3mm
TP8: 5V; TestPoint_Bridge_Pitch6.35mm_Drill1.3mm
TP10: 3.3V; TestPoint_Bridge_Pitch6.35mm_Drill1.3mm
TP13: Clock; TestPoint_Bridge_Pitch2.0mm_Drill0.7mm
TP14, TP17, TP20, TP23: 3.3V; TestPoint_Bridge_Pitch2.54mm_Drill0.7mm
TP15: MCU DVCC; TestPoint_Bridge_Pitch2.54mm_Drill0.7mm
TP16: MCU AVCC; TestPoint_Bridge_Pitch2.54mm_Drill0.7mm
TP18: 12V OUT; TestPoint_Bridge_Pitch2.54mm_Drill0.7mm
TP19: 12V IN; TestPoint_Bridge_Pitch2.54mm_Drill0.7mm
TP21: SD Card VCC; TestPoint_Bridge_Pitch2.54mm_Drill0.7mm
TP22: DP83848 VCC; TestPoint_Bridge_Pitch2.54mm_Drill0.7mm
TP24: 5V; TestPoint_Bridge_Pitch2.54mm_Drill0.7mm
TP25: Servo VCC; TestPoint_Bridge_Pitch2.54mm_Drill0.7mm
U1: STM32F407ZETx; LQFP-144_20x20mm_P0.5mm
U2: AT24C64; SOIC-8_3.9x4.9mm_P1.27mm
U3: LM2596 3.3V; TO-263-5_TabPin3
U4: LM2596 5V; TO-263-5_TabPin3
U5: LM35DZ(PA6); TO-92L_Inline
Y1: 12MHz; FT5HNBPK12.0-T1

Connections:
3.3VDDC: C4.2, C5.2, C6.2, C7.2, C8.2, C9.2, C10.2, C11.2, C12.2, C13.2, C14.2, C15.2, C34.1, C45.1, FB3.1, J1.6, J1.17, J1.18, J1.23, J1.36, J1.47, J1.58, J1.69, J2.6, J2.19, J2.32, J2.43, J2.55, J2.65, J9.1, J9.2, JP4.3, JP5.3, JP6.3, JP9.1, R7.1, R9.1, R10.1, R11.1, R13.2, R14.2, R17.1, TP2.1, U1.6 (VBAT), U1.17 (VDD), U1.30 (VDD), U1.39 (VDD), U1.52 (VDD), U1.62 (VDD), U1.72 (VDD), U1.84 (VDD), U1.95 (VDD), U1.108 (VDD), U1.121 (VDD), U1.131 (VDD), U1.143 (PDR_ON), U1.144 (VDD), U2.8 (VCC), U5.1 (+VS); also elsewhere on the board
3.3VOUT: C31.2, C35.1, C40.2, C41.1, C44.2, C46.1, J3.2, J3.9, J4.4, J5.2, J5.11, J6.1, J6.2, J6.3, J6.4, J18.1, J18.2, JP36.2 (B), JP37.2 (B), JP39.2 (B), JP40.1 (A), L4.2, TP4.1, TP14.1, TP17.1, TP20.1, TP23.1
5VOUT: C32.1, C39.1, J3.1, J3.10, J5.1, J5.12, J7.1, J7.2, J7.3, J7.4, J15.2, J17.5, JP43.2 (B), L3.2, R2.2, R16.2, RV4.3, TP3.1, TP24.1
12V: F1.1, JP38.2 (B), TP18.1
12VOUT: C17.1, C18.1, C19.1, C20.1, C33.1, C47.1, J8.1, J8.2, J8.3, J8.4, L5.2, R8.2, TP1.1, U3.1 (VIN), U4.1 (VIN)
32k: J17.1
+3V3: C27.1, C29.1, C42.1, L1.2, L4.1, R5.2, TP10.1, U3.4 (FB)
+5V: C28.1, C30.1, C36.1, L2.2, L3.1, R6.2, TP8.1, U4.4 (FB)
+12V: C43.1, JP38.1 (A), L5.1, TP6.1, TP19.1
A: J15.15, R16.1
A0: JP5.2, U2.1 (A0)
A1: JP4.2, U2.2 (A1)
A2: JP6.2, U2.3 (A2)
BOOT0: J1.11, JP9.2, U1.138 (BOOT0)
CD: J16.1, JP10.1 (A)
CLK: J16.5, JP14.1 (A)
CMD: J16.6, JP15.1 (A)
CRS: J14.14, JP27.2 (B)
CRX: J4.2, JP2.1 (A)
CTS: J21.2
CTX: J4.1, JP3.1 (A)
D0: J15.7
D1: J15.8
D2: J15.9
D3: J15.10
DP83848_Power: J14.19, J14.20, JP40.2 (B), TP22.1
DREQ: J18.7, JP33.1 (A)
DTR: J21.6
GND: C1.2, C2.2, C4.1, C5.1, C6.1, C7.1, C8.1, C9.1, C10.1, C11.1, C12.1, C13.1, C14.1, C15.1, C17.2, C18.2, C19.2, C20.2, C21.1, C22.1, C23.2, C24.1, C25.1, C26.2, C27.2, C28.2, C29.2, C30.2, C31.1, C32.2, C33.2, C34.2, C36.2, C39.2, C40.1, C41.2, C42.2, C43.2, C44.1, C45.2, C46.2, C47.2, C48.1, D1.1 (K), D2.1 (K), D3.1 (K), D4.1 (K), D5.1 (K), D6.2 (A), D7.2 (A), J1.3, J1.33, J1.55, J1.70, J2.7, J2.20, J2.33, J2.44, J2.66, J3.5, J3.6, J4.3, J5.6, J5.7, J9.3, J9.5, J9.7, J9.9, J9.11, J9.13, J9.15, J9.17, J9.19, J10.2, J10.3, J11.1, J11.2, J11.3, J11.4, J12.1, J12.2, J12.3, J12.4, J13.1, J13.2, J13.3, J13.4, J14.17, J14.18, J15.1, J15.5, J15.16, J16.8, J17.6, J18.3, J18.4, J19.3, J20.1, J20.3, J20.5, J20.7, J21.1, JP4.1, JP5.1, JP6.1, JP9.3, Q1.1 (C), R1.2, R15.2, RV1.1, RV2.1, RV3.1, RV4.1, SW1.3, SW1.4, SW2.3, SW2.4, SW3.3, SW3.4, SW4.3, SW4.4, SW5.3, SW5.4, TP7.1, TP9.1, TP11.1, TP12.1, U1.16 (VSS), U1.38 (VSS), U1.51 (VSS), U1.61 (VSS), U1.83 (VSS), U1.94 (VSS), U1.107 (VSS), U1.120 (VSS), U1.130 (VSS), U2.4 (GND), U2.7 (WP), U3.3 (GND), U3.5 (~ON/OFF), U4.3 (GND), U4.5 (~ON/OFF), U5.3 (GND); also elsewhere on the board
GNDA: C3.2, C16.1, C35.2, C37.2, C38.2, J1.50, U1.31 (VSSA), Y1.1 (NC), Y1.2 (GND); also elsewhere on the board
MDC: J14.16, JP28.2 (B)
MDIO: J14.15, JP20.2 (B)
MISO_1: J1.7, J5.4, JP29.2 (B), U1.134 (PB4)
MISO_2: J2.52, J5.9, U1.75 (PB14)
MOSI_1: J1.10, J5.3, JP30.2 (B), U1.135 (PB5)
MOSI_2: J1.48, J5.10, U1.29 (PC3)
unnamed: BZ1.1 (-), R2.1
unnamed: BZ1.2 (+), Q1.3 (E)
unnamed: C23.1, C26.1, D8.1 (K), F1.2
unnamed: D1.2 (A), R5.1
unnamed: D2.2 (A), R3.2
unnamed: D3.2 (A), R4.2
unnamed: D4.2 (A), R6.1
unnamed: D5.2 (A), R8.1
unnamed: D6.1 (K), L1.1, U3.2 (OUT)
unnamed: D7.1 (K), L2.1, U4.2 (OUT)
unnamed: D8.2 (A), J10.1
unnamed: FB3.2, JP36.1 (A), TP15.1
unnamed: J18.6, JP29.1 (A)
unnamed: J18.8, JP30.1 (A)
unnamed: J18.10, JP31.1 (A)
unnamed: J18.12, JP32.1 (A)
unnamed: J19.2, JP43.1 (A), TP25.1
OSCIN: J14.13, JP21.2 (B)
PA0: C21.2, J1.51, R7.2, SW1.1, SW1.2, U1.34 (PA0)
PA1: J1.54, JP21.1 (A), U1.35 (PA1)
PA2: J1.53, JP20.1 (A), U1.36 (PA2)
PA3: C24.2, J1.56, R10.2, SW3.1, SW3.2, U1.37 (PA3)
PA4: J1.57, U1.40 (PA4)
PA5: J1.60, J5.5, JP31.2 (B), U1.41 (PA5)
PA6: J1.59, U1.42 (PA6), U5.2 (VOUT)
PA7: J1.62, JP27.1 (A), U1.43 (PA7)
PA8: J2.27, U1.100 (PA8)
PA9: J2.26, JP42.2 (B), U1.101 (PA9)
PA10: J2.25, JP41.2 (B), U1.102 (PA10)
PA11: J2.24, JP2.2 (B), U1.103 (PA11)
PA12: J2.23, JP3.2 (B), U1.104 (PA12)
PA15: J2.17, J20.2, U1.110 (PA15)
PB0: J1.63, U1.46 (PB0)
PB1: J1.66, RV1.2, U1.47 (PB1)
PB2: C22.2, J1.65, R9.2, SW2.1, SW2.2, U1.48 (PB2)
PB6: J1.9, J3.4, JP7.2 (B), JP18.2 (B), U1.136 (PB6)
PB7: J1.12, J3.3, JP8.2 (B), JP19.2 (B), U1.137 (PB7)
PB8: J1.14, U1.139 (PB8)
PB9: J1.13, JP32.2 (B), U1.140 (PB9)
PB10: J2.58, J5.8, U1.69 (PB10)
PB11: J2.57, JP23.1 (A), U1.70 (PB11)
PB12: J2.54, JP25.1 (A), U1.73 (PB12)
PB13: J2.53, JP24.1 (A), U1.74 (PB13)
PB15: J2.51, U1.76 (PB15)
PC0: J1.43, RV2.2, U1.26 (PC0)
PC1: J1.46, JP28.1 (A), U1.27 (PC1)
PC2: J1.45, RV3.2, U1.28 (PC2)
PC4: J1.61, JP22.1 (A), U1.44 (PC4)
PC5: J1.64, JP26.1 (A), U1.45 (PC5)
PC6: J2.31, Q1.2 (B), R1.1, U1.96 (PC6)
PC7: J2.30, U1.97 (PC7)
PC8: J2.29, JP16.2 (B), U1.98 (PC8)
PC9: J2.28, JP11.2 (B), U1.99 (PC9)
PC10: J2.16, JP12.2 (B), U1.111 (PC10)
PC11: J2.15, JP13.2 (B), U1.112 (PC11)
PC12: J2.14, JP14.2 (B), U1.113 (PC12)
PC13: J1.26, U1.7 (PC13)
PC14: J1.25, U1.8 (PC14)
PC15: J1.28, U1.9 (PC15)
PD0: J2.13, U1.114 (PD0)
PD1: J2.12, JP10.2 (B), U1.115 (PD1)
PD2: J2.11, JP15.2 (B), U1.116 (PD2)
PD3: J2.10, U1.117 (PD3)
PD4: J2.9, U1.118 (PD4)
PD5: J2.8, U1.119 (PD5)
PD6: J2.5, U1.122 (PD6)
PD7: J2.4, U1.123 (PD7)
PD8: J2.50, U1.77 (PD8)
PD9: J2.49, U1.78 (PD9)
PD10: J2.48, U1.79 (PD10)
PD11: J2.47, U1.80 (PD11)
PD12: J2.46, J20.6, U1.81 (PD12)
PD13: J2.45, J19.1, U1.82 (PD13)
PD14: J2.42, J20.4, U1.85 (PD14)
PD15: J2.41, J15.14, U1.86 (PD15)
PE0: J1.16, U1.141 (PE0)
PE1: J1.15, U1.142 (PE1)
PE2: J1.20, U1.1 (PE2)
PE3: J1.19, U1.2 (PE3)
PE4: J1.22, U1.3 (PE4)
PE5: J1.21, U1.4 (PE5)
PE6: J1.24, U1.5 (PE6)
PE7: J2.69, U1.58 (PE7)
PE8: J2.68, U1.59 (PE8)
PE9: J2.67, U1.60 (PE9)
PE10: J2.64, U1.63 (PE10)
PE11: J2.63, U1.64 (PE11)
PE12: J2.62, U1.65 (PE12)
PE13: J2.61, U1.66 (PE13)
PE14: J2.60, U1.67 (PE14)
PE15: J2.59, U1.68 (PE15)
PF0: J1.27, J3.7, U1.10 (PF0)
PF1: J1.30, J3.8, U1.11 (PF1)
PF2: J1.29, U1.12 (PF2)
PF3: J1.32, U1.13 (PF3)
PF4: C48.2, J1.31, R17.2, SW5.1, SW5.2, U1.14 (PF4)
PF5: J1.34, JP17.2 (B), U1.15 (PF5)
PF6: J1.35, JP33.2 (B), U1.18 (PF6)
PF7: J1.38, JP34.2 (B), U1.19 (PF7)
PF8: J1.37, JP35.2 (B), U1.20 (PF8)
PF9: J1.40, U1.21 (PF9)
PF10: J1.39, R12.1, R15.1, U1.22 (PF10)
PF11: J1.68, U1.49 (PF11)
PF12: J1.67, U1.50 (PF12)
PF13: J1.72, U1.53 (PF13)
PF14: J1.71, U1.54 (PF14)
PF15: J2.72, U1.55 (PF15)
PG0: J2.71, U1.56 (PG0)
PG1: J2.70, U1.57 (PG1)
PG2: J2.40, J15.13, U1.87 (PG2)
PG3: J2.39, J15.12, U1.88 (PG3)
PG4: J2.38, J15.11, U1.89 (PG4)
PG5: J2.37, J15.6, U1.90 (PG5)
PG6: J2.36, J15.4, U1.91 (PG6)
PG7: J2.35, U1.92 (PG7)
PG8: J2.34, U1.93 (PG8)
PG9: J2.3, U1.124 (PG9)
PG10: J2.2, U1.125 (PG10)
PG11: J2.1, U1.126 (PG11)
PG12: J1.2, U1.127 (PG12)
PG13: J1.1, R4.1, U1.128 (PG13)
PG14: J1.4, R3.1, U1.129 (PG14)
PG15: J1.5, U1.132 (PG15)
RCC_OSC_IN: J1.42, TP13.1, U1.23 (PH0), Y1.3 (OUT)
RCC_OSC_OUT: J1.41, U1.24 (PH1)
RX0: J14.11, JP22.2 (B)
RX1: J14.12, JP26.2 (B)
Reset: C25.2, J1.44, J9.16, R11.2, SW4.1, SW4.2, U1.25 (NRST)
SCL: JP7.1 (A), R13.1, U2.6 (SCL)
SCL_DS: J17.3, JP18.1 (A)
SDA: JP8.1 (A), R14.1, U2.5 (SDA)
SDA_DS: J17.4, JP19.1 (A)
SDIO_D0: J16.7, JP16.1 (A)
SDIO_D1: J16.2, JP11.1 (A)
SDIO_D2: J16.3, JP12.1 (A)
SDIO_D3: J16.4, JP13.1 (A)
SD_Card_Power: J16.9, JP39.1 (A), TP21.1
SQW: J17.2, JP17.1 (A)
SWCLK: J2.18, J9.10, U1.109 (PA14)
SWDIO: J2.22, J9.8, U1.105 (PA13)
SWO: J1.8, J9.14, U1.133 (PB3)
TX0: J14.10, JP25.2 (B)
TX1: J14.7, JP24.2 (B)
TX_EN: J14.9, JP23.2 (B)
UART_RX: J21.5, JP42.1 (A)
UART_TX: J21.4, JP41.1 (A)
VCAP2: C2.1, J2.21, U1.106 (VCAP_2)
VCAP_1: C1.1, J2.56, U1.71 (VCAP_1)
VCC: J21.3
VO: J15.3, RV4.2
xDCS: J18.11, JP35.1 (A)
xRESET: J18.9, JP34.1 (A)

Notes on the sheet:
Pin Out
PWM
CLCD
I2C(DS3231)
ETH(DP83848)
EEPROM
UART
SD Card
BOOT Mode
Analog
Power
Temp
VS1003
Buzzer
CAN
TCXO 12.000MHz
Reset
Servo
I2C, SPI
SWD

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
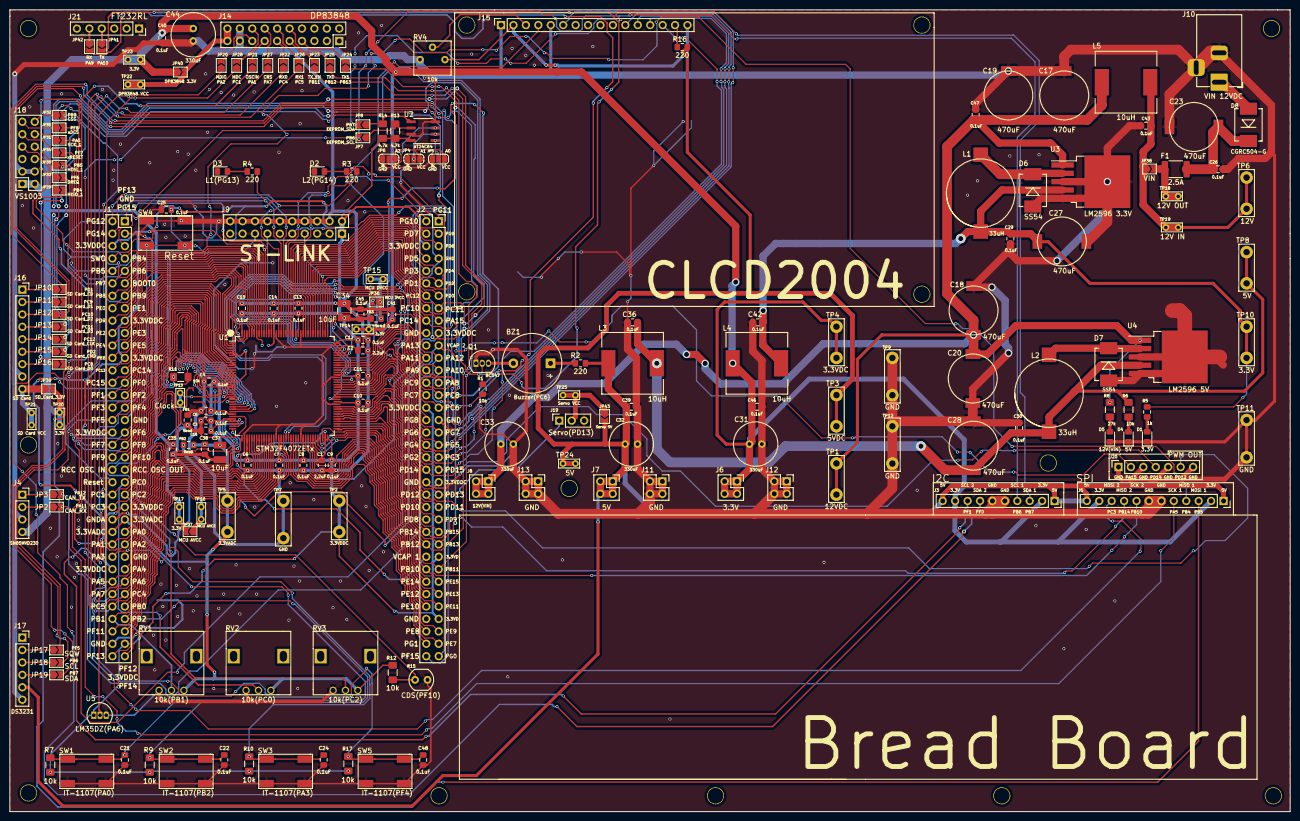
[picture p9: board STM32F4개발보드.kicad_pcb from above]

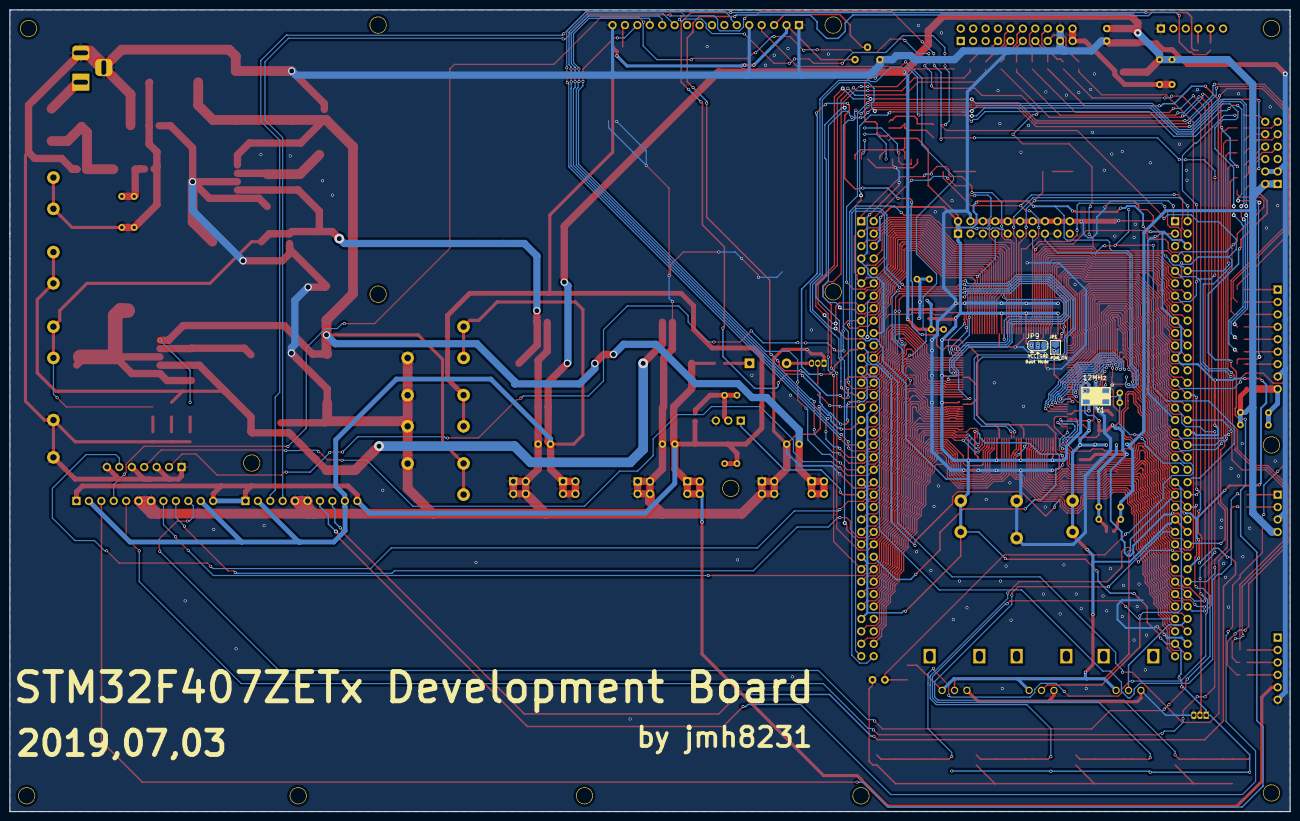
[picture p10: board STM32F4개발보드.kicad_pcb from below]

Board: 2 copper layers, 261.6 x 163.8 mm, 202 parts (3 on the bottom side), 182 nets.

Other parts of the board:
 : h
 #2,  #3,  #4,  #5,  #6,  #7,  #8,  #9,  #10,  #11,  #12,  #13,  #14: h
FB1: Bead; L_0805_2012Metric_Pad1.15x1.40mm_HandSolder
JP1: PDR_ON; SolderJumper-2_P1.3mm_Open_TrianglePad1.0x1.5mm

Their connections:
3.3VDDC: JP1.2; also elsewhere on the board
GND: FB1.2; also elsewhere on the board
GNDA: FB1.1; also elsewhere on the board

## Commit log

2025-08-25 STM32 Dev Board HW v1.0
    [STM32F4개발보드.kicad_pcb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]
2025-08-25 add hw v1.0
    [STM32F4개발보드.kicad_pcb, STM32F4개발보드.kicad_sch, STM32F4개발보드.sch]
2025-08-25 add hw v2.0
    [ARM 세미나 보드 Bom.csv, ARM 세미나 보드.kicad_pcb, ARM 세미나 보드.kicad_sch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]
